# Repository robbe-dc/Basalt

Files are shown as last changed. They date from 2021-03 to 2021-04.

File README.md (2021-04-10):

# Basalt is an open source vertical computer case

Basalt was created as an open source, DIY alternative to popular SFF cases on the market. The aim is to create a small computer case with emphasis on tiny desk footprint, while still supporting today's hardware.

Basalt is made out of easy to source/create materials so it is easy to make it yourself. The main things you need are (access to) a 3D printer and a laser cutter. If you do not own these machines and do not have access to them, I advice you to try a local fablab or use online services like Shapeways, i.materialise and others.

## Hardware support

Hardware support is as following:

* ITX motherboard
* 48mm CPU cooler
* SFX(L) PSU support
* Top mounted 120mm fan
* 2x 2.5" drives up to 9mm thick
* GPU:
  * 60mm thick (3 slots) as long as the PCI bracket is 1 or 2 slot
  * 140mm high plus an extra 16mm for power connectors
  * 325mm length without top fan, 321mm with 15mm top fan, 311mm with 25mm top fan

## Getting started

* Source the materials from the [shopping list](docs/SHOPPINGLIST.md)
* Read about the [preparations](docs/PREPARATIONS.md)
* Print the required parts
* Lasercut the panels
* Build the case using the [assembly guide](docs/ASSEMBLY.md)

## Contribute

This case is open source thus contributions are encouraged. Feel free to fork this projects and create a pull request if wanted. You can also open an issue if you have aditional questions or remarks.

## Contact

Contacting me is easiest on the forum of smallforfactor.net: [Visit my profile](https://smallformfactor.net/forum/members/robbee.801/)

You can also follow the progress and discussion of the case there: [View the thread](https://smallformfactor.net/forum/threads/9l-vertical-case-that-supports-long-3-slot-graphics-card.15892)

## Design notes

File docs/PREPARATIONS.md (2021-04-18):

# Preparing the parts

Looks like you've succeeded collecting all required parts, which is a challenge to start with. Well done! Now let's get building.

## Glueing the magnets

The printed parts have a recess where the magnet will need to be glued. The smaller part hold the magnet that is glued to the 3D printed part, the larger part holds the magnet that is glued to the case panel.

The glue I used was 'UHU Max Repair' and this worked well.

To attach the magnets to the panels on the correct position, you can make use of the printed glue mold in the optional parts. You will need at least 1 normal and 1 reverse version. Refer to the image to see how to use them (most important is the position of the middle magnet as it's not symetrical).

**Important:** Make sure to triple check the polarity of the magnets before glueing. You also want to have the same polarity across all parts because the side panels are interchangable.

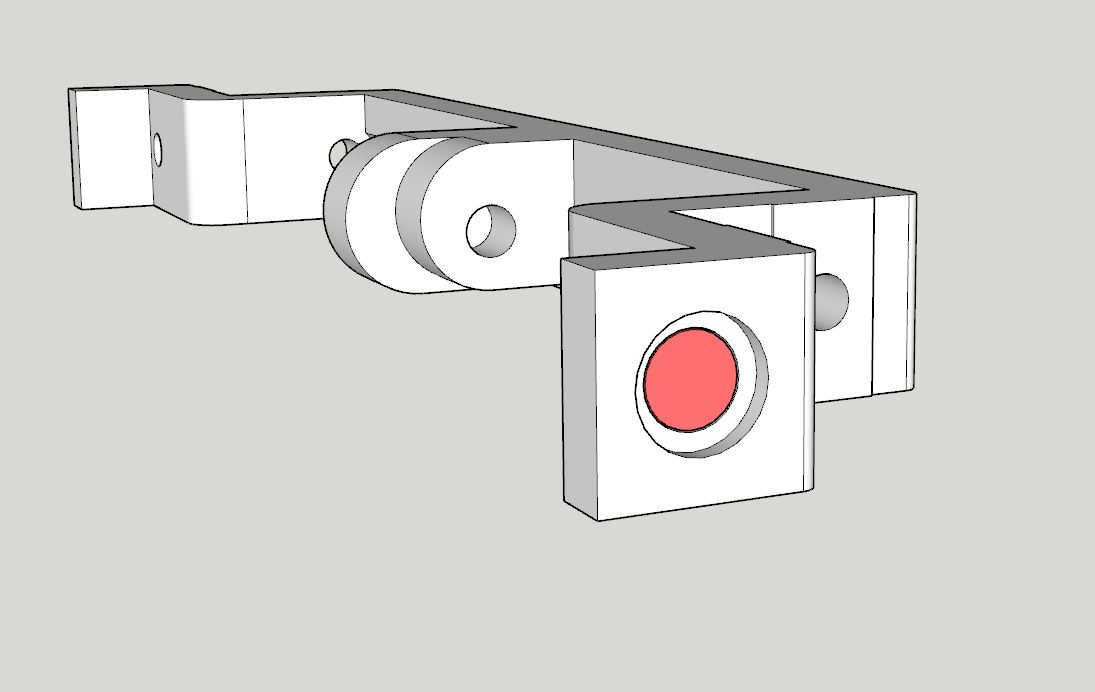
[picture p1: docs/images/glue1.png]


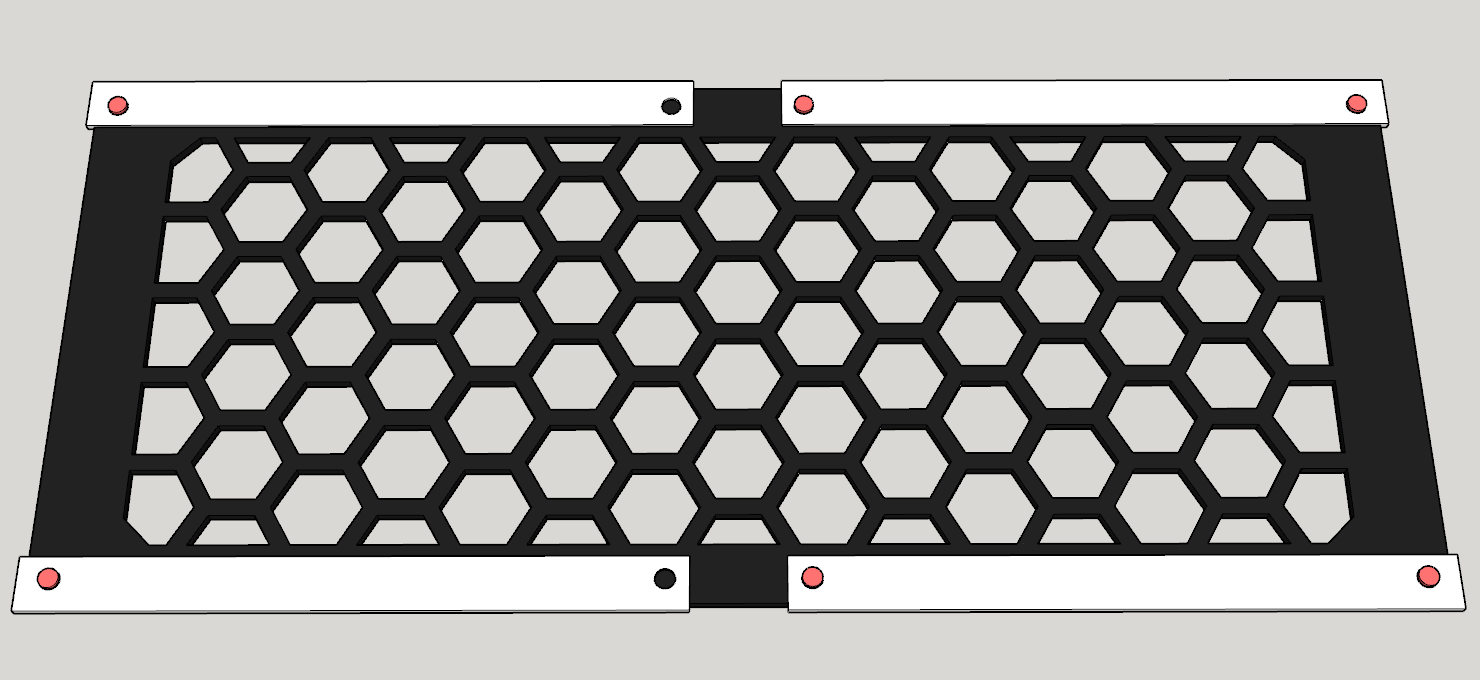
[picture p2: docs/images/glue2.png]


## Inserting threaded inserts

Threaded inserts are melted into certain parts with a soldering iron so we can screw into them without wearing out the plastic.

For a general guide about inserting threaded inserts, refer to the following movie: https://www.youtube.com/watch?v=GP1qrN-ONTA
However, I would advice you to not use so much force pushing in the inserts as we're working with smaller ones.

There are several pieces that require threaded inserts:

### Bottom

The bottom requires the following inserts:

* 2x 4mm inserts for the front IO
* 2x 4mm inserts for the GPU PCI tab
* 2x 3mm inserts for the GPU PCI clamp (above the video outputs)

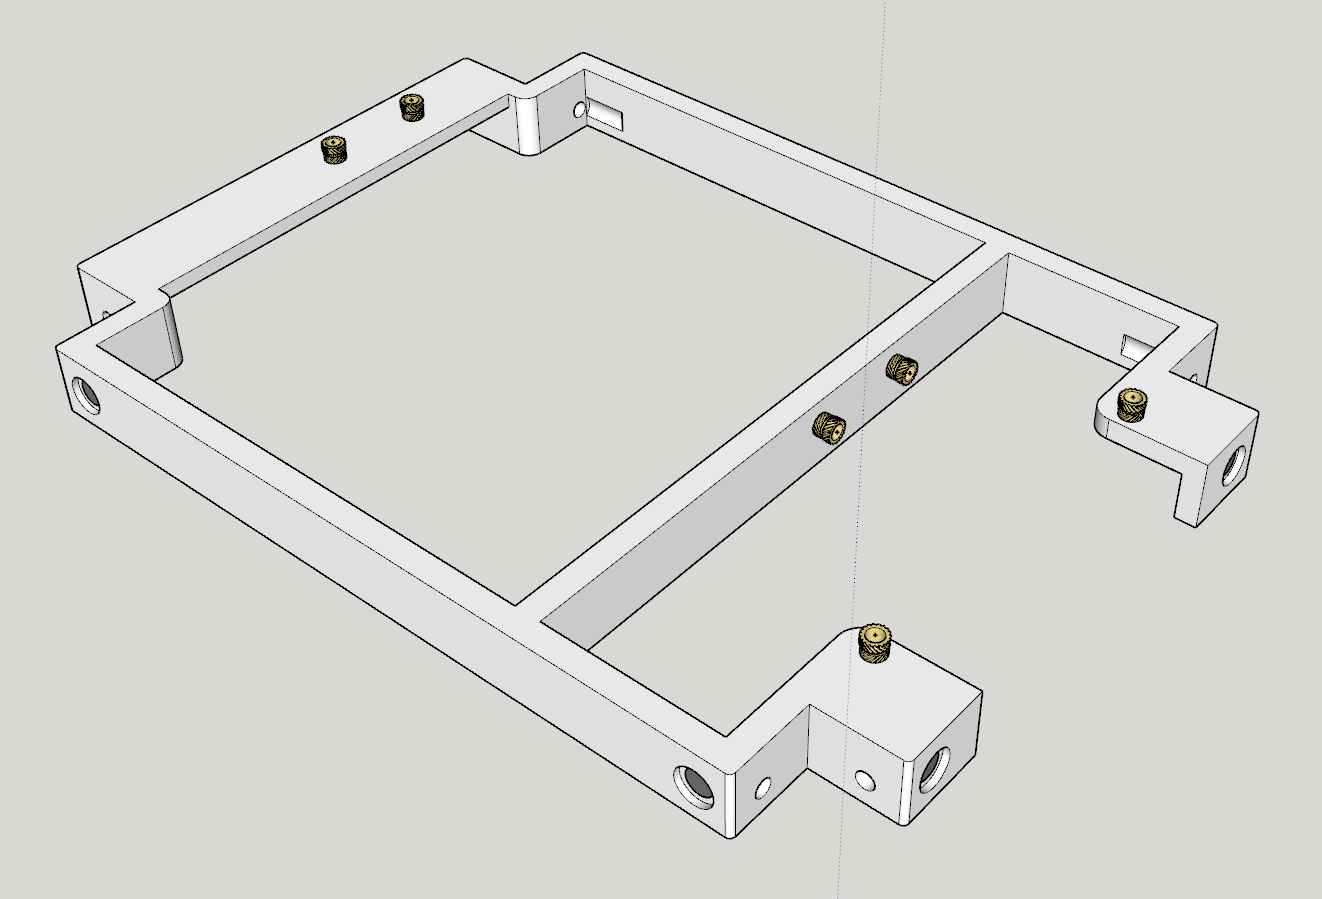
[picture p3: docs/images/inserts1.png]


### PSU Bottom

The PSU bottom needs one insert for the riser.

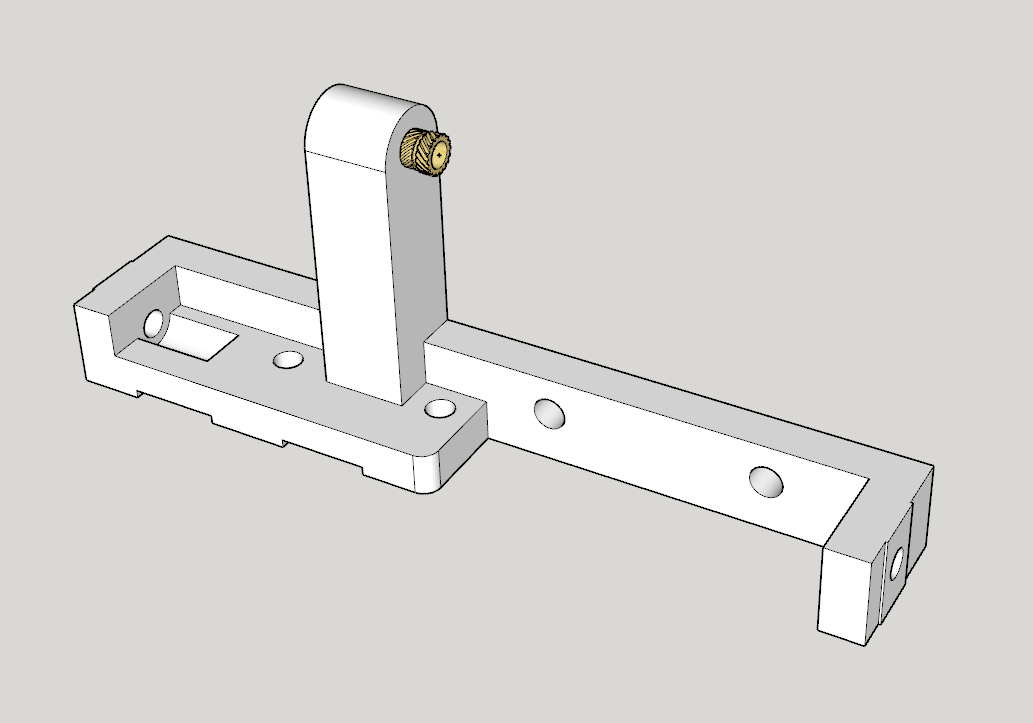
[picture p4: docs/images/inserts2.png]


### Motherboard parts x3

The three individual motherboard parts all need inserts to mount the motherboard. Make sure you check what the front and the back are so you insert the the right direction. The top of the insert should be the non-chamfered edge because that's where the motherboard comes.

The motherboard bottom back part also needs an insert for the riser.

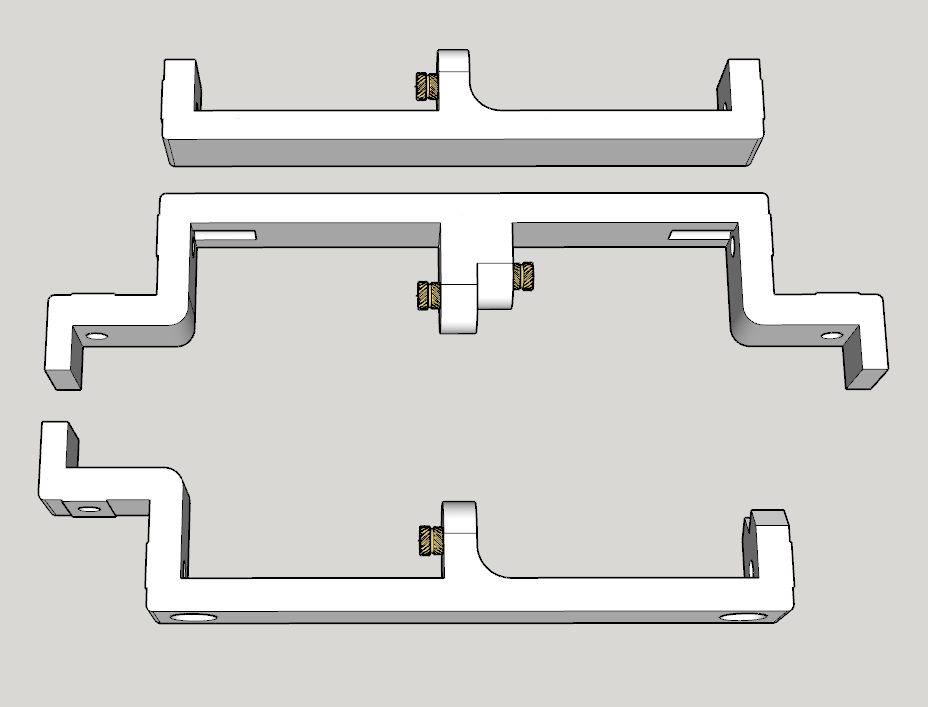
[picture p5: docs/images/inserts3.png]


### Top

Finally, the top also needs one insert for the last motherboard mount. There is no way of checking for non-chamfered sides here, but you can make out the sides because this part is not symmetrical.

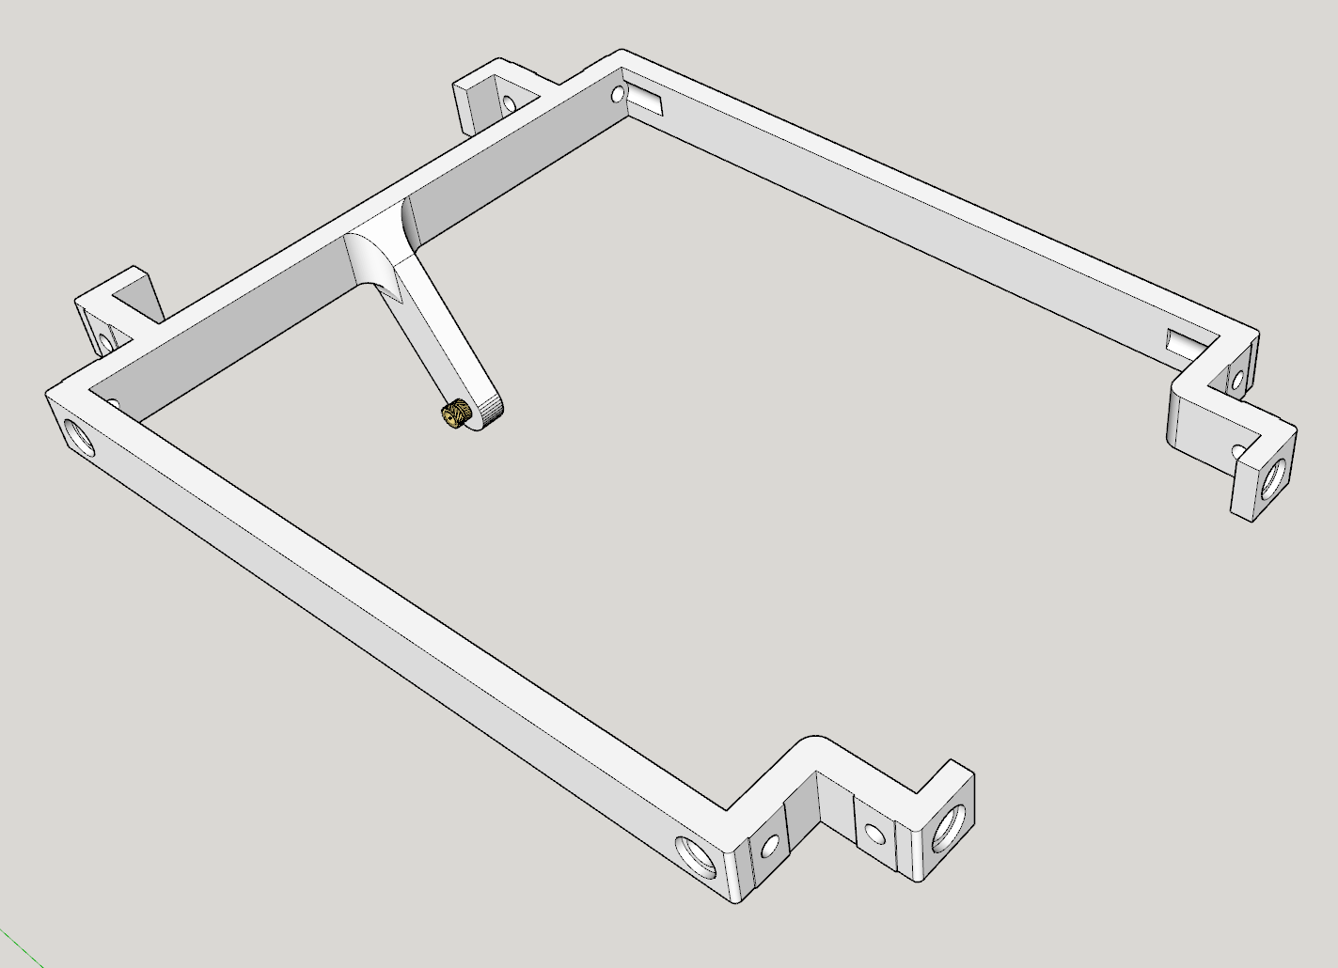
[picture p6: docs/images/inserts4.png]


## Attaching the T-nuts

The T-slot nuts will slide into the extrusion and the printed parts are then screwn into the nuts. This is hard to do when the nuts slide all over the place, so I prefer to attach the nuts to the parts before sliding them into the extrusion.

You can do so by screwing the nuts to the part with the M3x10mm screws, but don't tighten it yet as you won't be able to slide them in the extrusion anymore. Do this for all parts that require T-slot nuts, which are the following:

* Bottom: 8 nuts
* PSU bottom: 2 nuts
* PSU top: 1 nut
* Motherboard bottom back: 4 nuts
* Motherboard bottom front: 3 nuts + 1 nut for the optional piece
* Motherboard top front: 2 nuts
* Top: 8 nuts
* (optional) GPU holder: 2 nuts (see opional pieces for more info)

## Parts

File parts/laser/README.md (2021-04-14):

# Laser cut panels

You will need to cut these 6 panels out of 3mm thick acrylic or wood. The dimensions can be found in the readme file of each panel

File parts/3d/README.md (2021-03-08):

# 3D printed parts

This folder contains each required 3D printed part for the case. Each folder has its own readme file with print instructions for the specific file.

## Print settings and material

Preferably, print this in PETG with at least 3 perimeters. Infill won't matter a lot because there is so little of it.

I have also made versions in PLA but found them to be a bit too brittle and the adhesion between layers was a bit too weak to withstand the force of the screws.

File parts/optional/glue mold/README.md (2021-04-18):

# Glue mold

This mold is used to align the magnet on the panels when glueing them. Refer to the [preparations](../../../docs/PREPARATIONS.md) documentation for info on how to use it.

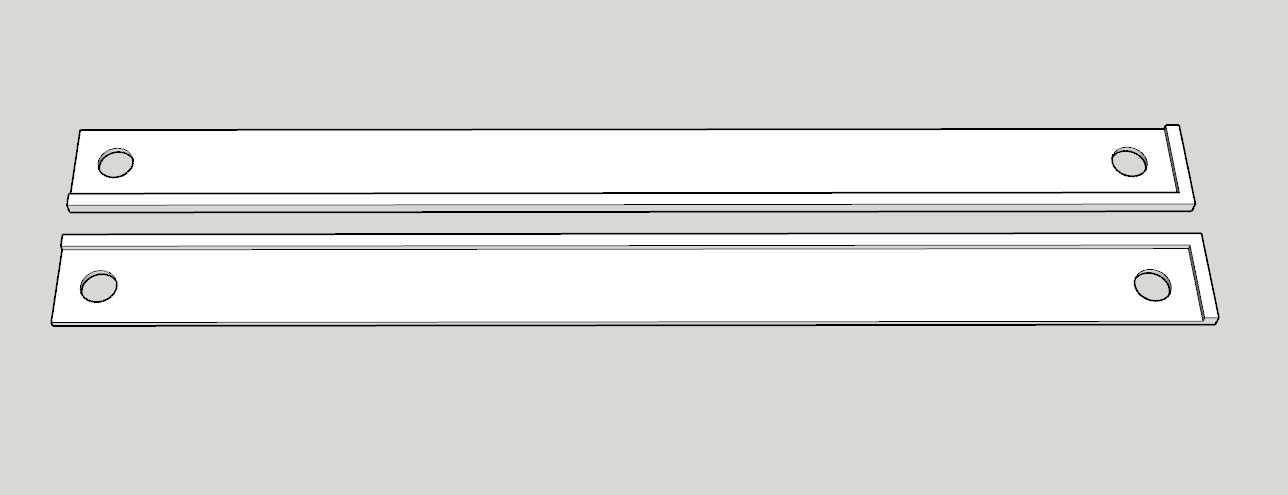
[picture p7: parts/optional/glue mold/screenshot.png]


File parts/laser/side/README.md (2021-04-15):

# Side panel

This panel is symmetric so you cut one for each side.

Width: 147mm
Height: 350mm

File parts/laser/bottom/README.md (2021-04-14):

# Bottom panel

Width: 188mm
Height: 137mm

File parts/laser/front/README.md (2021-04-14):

# Front panel

Width: 96mm
Height: 350mm

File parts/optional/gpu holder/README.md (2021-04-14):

# GPU holder

This is a special part that can be used to mount the rear of the GPU to the case so it is very firmly held into place. This requires your GPU to have special mounting points used for server mounting. Most Nvidia GPU's have those mouning points and some AMD cards as well.

Those screw holes are usually M3 and you best use countersunk screws to avoind interferance with the top fan.

To know if your GPU has these mounting points, refer to the following images:

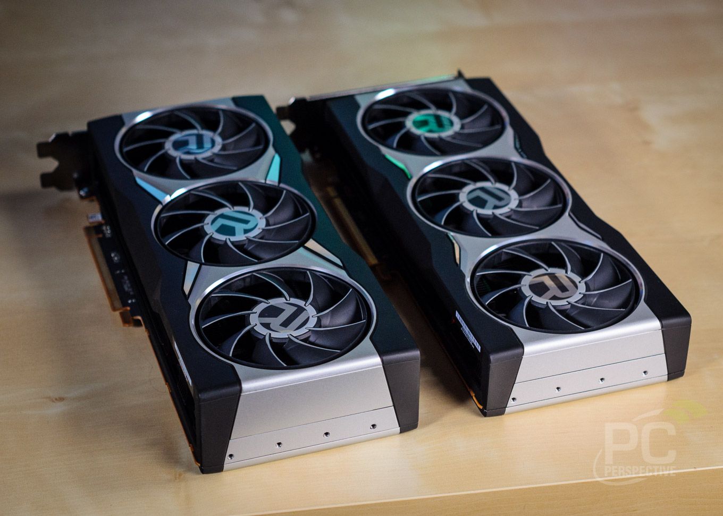
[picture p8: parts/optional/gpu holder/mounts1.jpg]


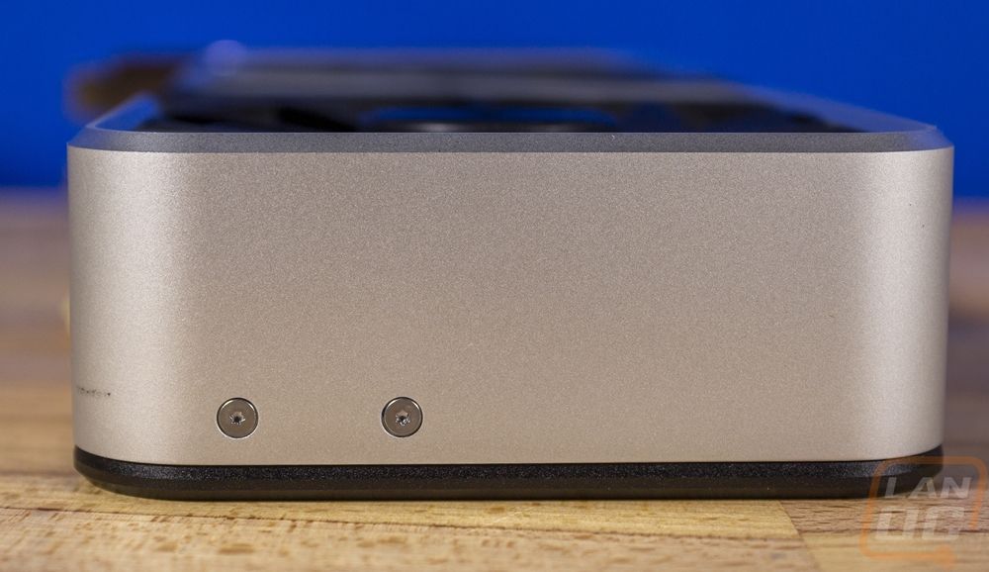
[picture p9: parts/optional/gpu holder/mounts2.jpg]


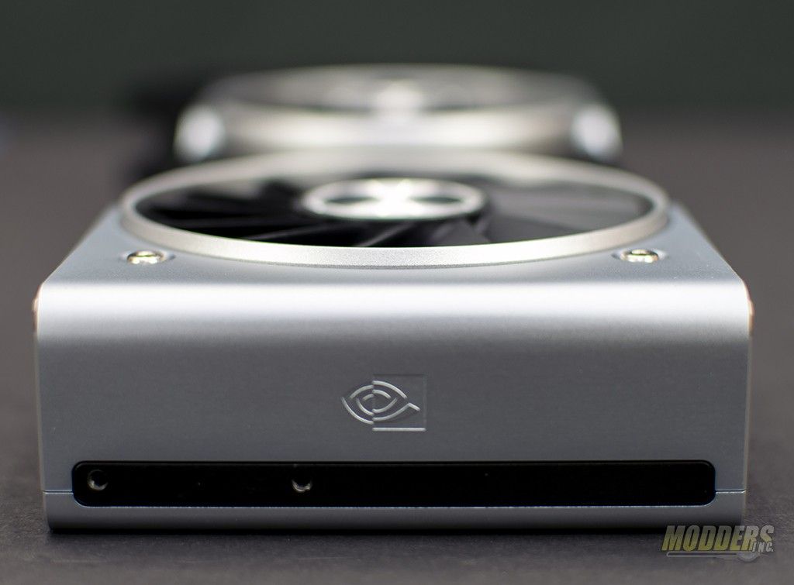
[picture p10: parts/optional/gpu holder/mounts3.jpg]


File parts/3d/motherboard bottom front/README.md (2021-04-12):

# Motherboard bottom front

This part connects the motherboard bottom front to the 2 front extrusions and has room for 4 magnets for the front and 2 side panels.

This part is split up in 2 parts so that you can ommit the smaller part when you have a very tall and thick GPU.

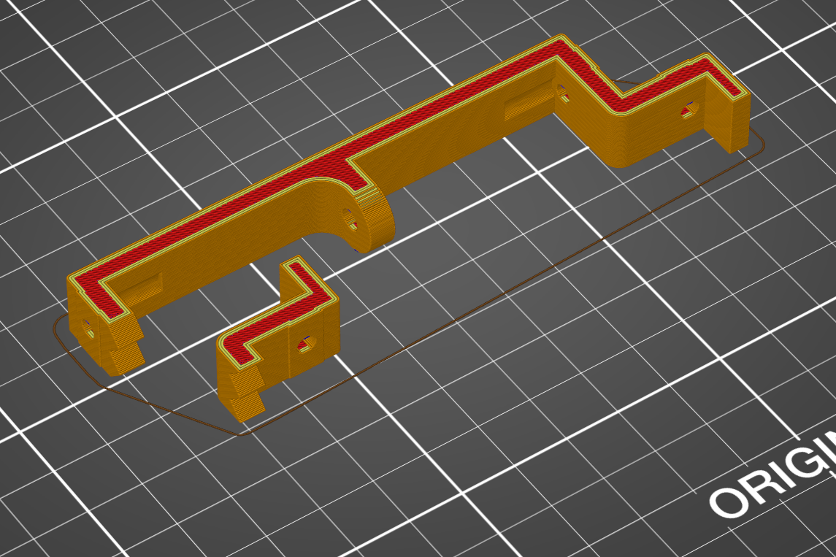
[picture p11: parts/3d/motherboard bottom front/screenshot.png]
Slicer screenshot


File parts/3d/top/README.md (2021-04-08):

# Top

This important part holds the 4 extrusions together, holds 8 magnets for all panels and supports the top back corner of the motherboard.

This part is pretty easy to print. No support required, a brim of about 5mm could be prefered if your printer is prone to prints warping.

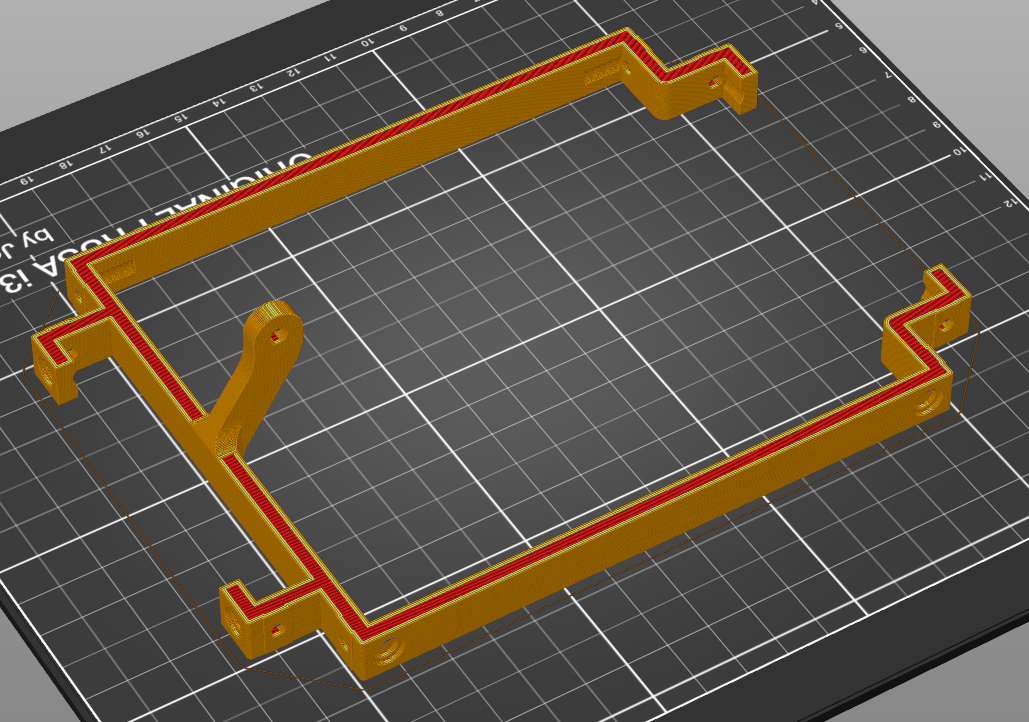
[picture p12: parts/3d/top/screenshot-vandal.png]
Slicer screenshot


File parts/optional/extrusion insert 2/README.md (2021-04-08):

# Extrusion insert 2

This insert should be printed twice and goes in the front top, between the motherboard bottom front and the motherboard top front.

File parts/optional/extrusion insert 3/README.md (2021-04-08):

# Extrusion insert 3

This insert goes in the back bottom, between the PSU bottom and the PSU top.

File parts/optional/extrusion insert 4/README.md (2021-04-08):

# Extrusion insert 4

This insert goes in the back bottom, between the PSU bottom and the motherboard bottom back.

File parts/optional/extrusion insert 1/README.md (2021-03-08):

# Extrusion insert 1

This insert should be printed twice and goes in the bottom front, between the bottom and the motherboard bottom front parts.

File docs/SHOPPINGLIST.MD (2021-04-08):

# Items required for the Basalt:

Note: items that are used in high numbers include some spares.

Item | Amount | Size | Note
---- | ------ | ---- | ----
GPU riser|1|About 18cm long|Any riser with 108mm hole spacing that is either straight or double reverse (eg. ADT-Link, Li-Heat, Linkup)
Video output extensions|1 or 2|5 to 10 cm|Important: refer to the [guide](#about-the-video-extension-cables) under this table for more info
Rounded aluminium extrusions|4|350mm long, 20x20|Can be bought on [Motedis](https://www.motedis.com/shop/Aluprofile/Aluprofil-20x20-LR-B-Typ-Nut-6::4.html) (EU), [Misumi](https://us.misumi-ec.com/vona2/detail/110302685570/?Tab=codeList) (US), [Aliexpress](https://nl.aliexpress.com/item/32837930160.html)
T-slot inserts|About 30|Preferably M3|Best get some spares. Can be bought on Motedis (EU), Misumi (US), Aliexpress
Case feet|4|Depends on the tap size of your extrusions|I used [these](https://aliexpress.com/item/4001184672773.html?) (M6*15). Smaller taps can also use feet like [these](https://aliexpress.com/item/33060530969.html)
Round magnets|About 50|5mm diameter, 1mm thick|
Threaded inserts|8|M3, 4mm long|[Aliexpress](https://aliexpress.com/item/4001258499799.html)
Threaded inserts|2|M3, 3mm long|[Aliexpress](https://aliexpress.com/item/4001258499799.html)
Screws|10|M3 x 5mm|Non countersunk, philips head
Screws|About 40|M3 x 10mm|Non countersunk, philips head
Screws|4|M4 x 10mm|Countersunk
Screws|8|The size of your extrusion taps

## About the video extension cables

The video extension cables come from ADT-Link. You should buy cables that have an angled male connector form your GPU on one side and a threaded female connector on the other side. ADT-Link connectors are easy to find on Aliexpress.

When using 1 cable, the cable should be 5cm long and it doesn't really mather what angle you pick. I went with a 5cm P3 to P4T displayport cable.

When using 2 cables, it gets a bit more complicated. The first cable should be 5cm long and the angle isn't too important again. The second cable should use the opposite angle and should be 10cm long. This allows for much easier cable routing because they don't have to cross eachother.

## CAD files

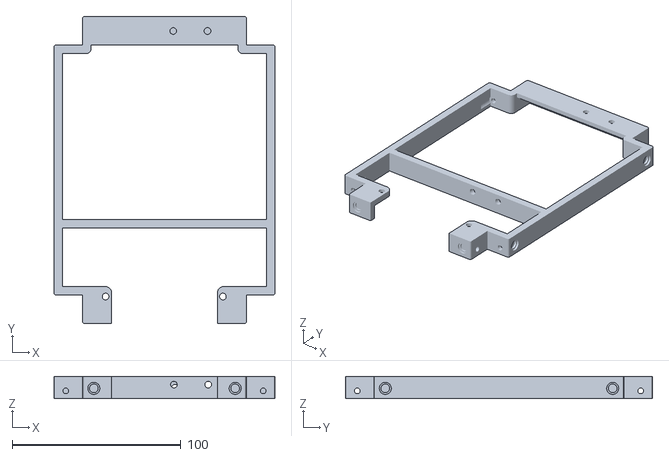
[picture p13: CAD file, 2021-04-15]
parts/3d/bottom/bottom.stl
131.0 x 182.0 x 13.2

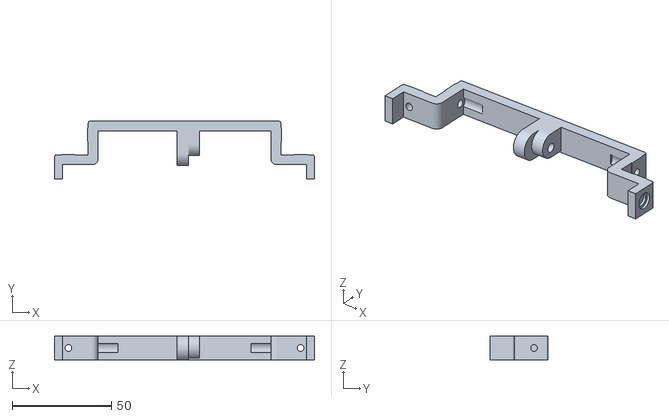
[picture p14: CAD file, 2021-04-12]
parts/3d/motherboard bottom back/motherboard bottom back.stl
131.0 x 29.2 x 12.0

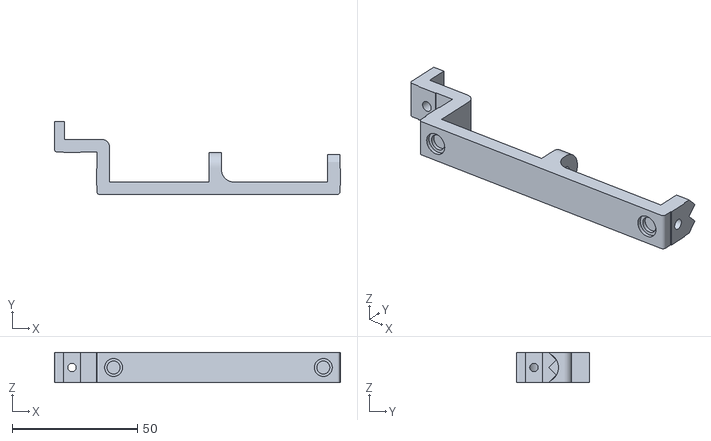
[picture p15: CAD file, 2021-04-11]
parts/3d/motherboard bottom front/motherboard bottom front.stl
114.3 x 29.2 x 12.0

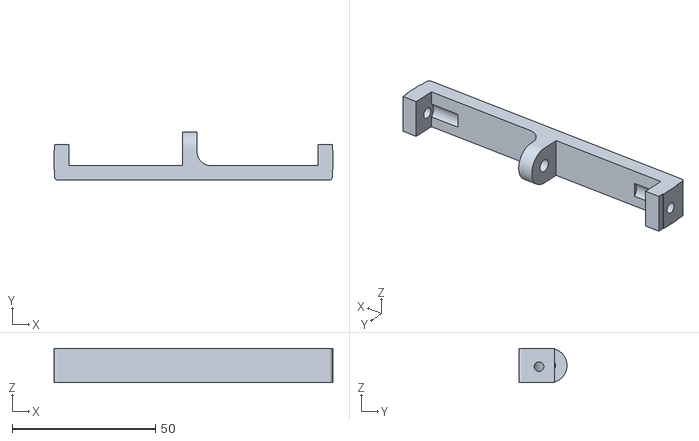
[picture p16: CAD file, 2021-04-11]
parts/3d/motherboard top front/motherboard top front.stl
97.5 x 16.8 x 12.0

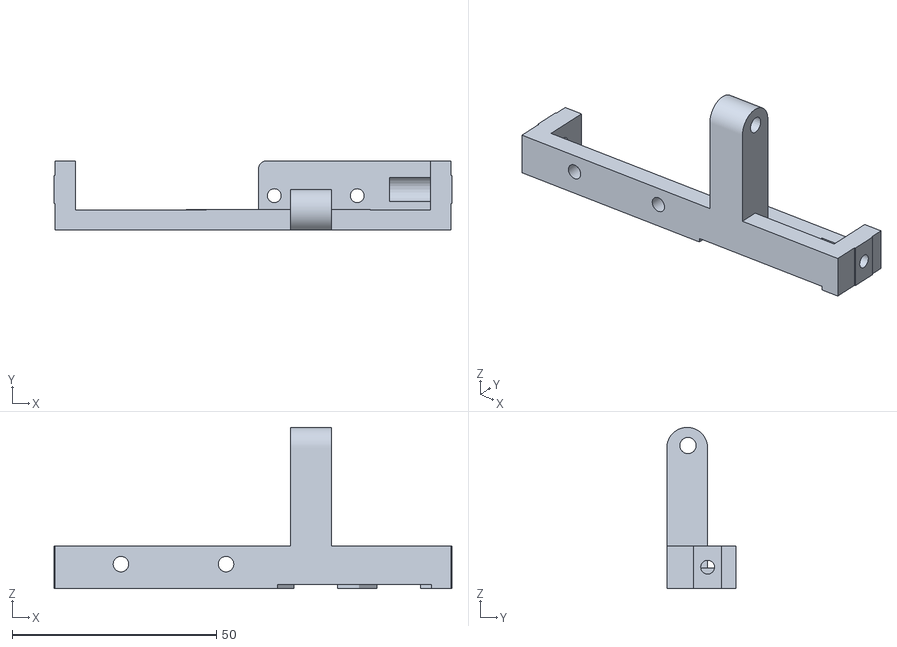
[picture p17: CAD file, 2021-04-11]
parts/3d/psu bottom/psu bottom.stl
97.5 x 17.0 x 39.5

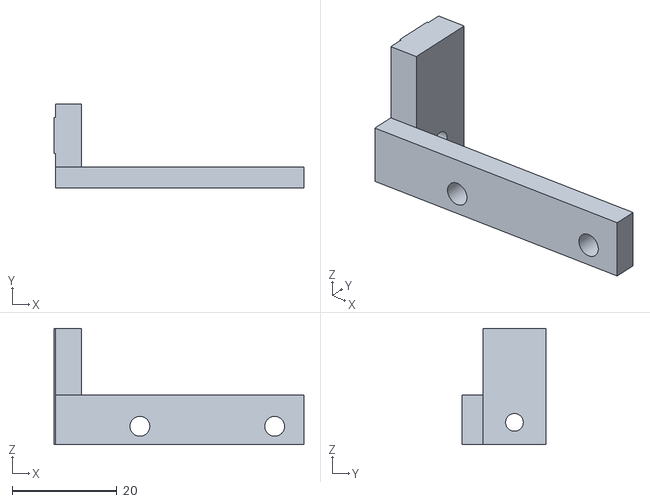
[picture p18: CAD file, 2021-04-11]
parts/3d/psu top/psu top.stl
47.8 x 16.0 x 22.2

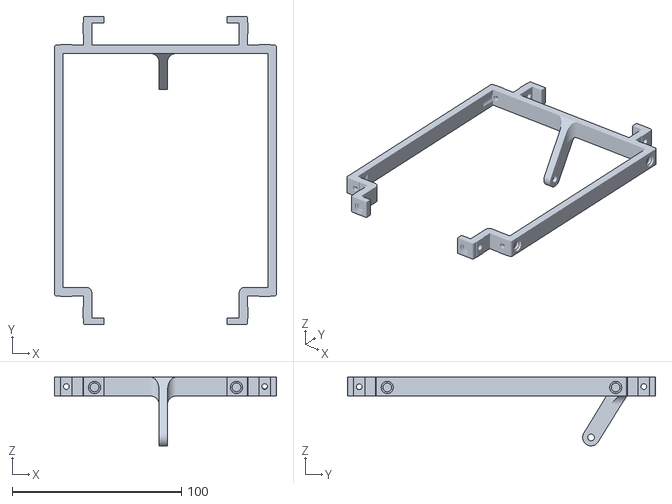
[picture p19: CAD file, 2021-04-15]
parts/3d/top/top.stl
131.0 x 182.0 x 40.6

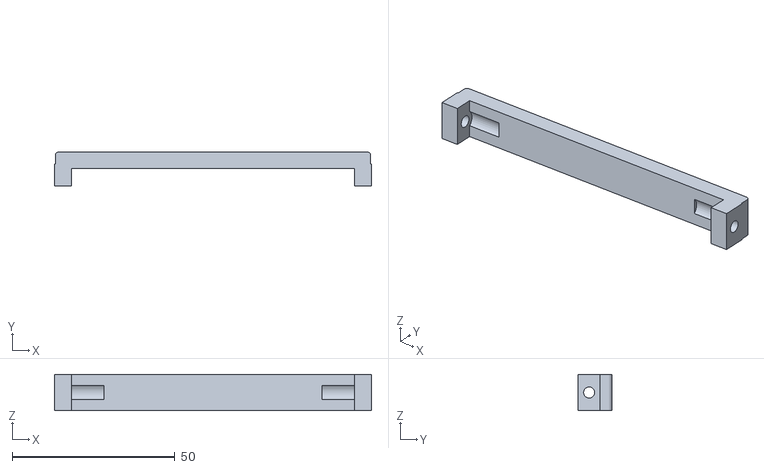
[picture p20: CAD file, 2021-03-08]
parts/optional/cable holder/cable holder.stl
97.5 x 10.4 x 11.2

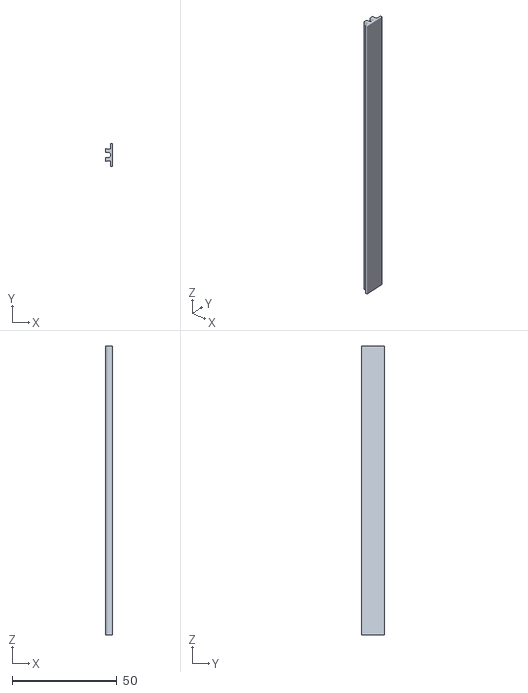
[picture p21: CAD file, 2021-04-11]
parts/optional/extrusion insert 1/extrusion insert 1.stl
3.50 x 10.8 x 137.7

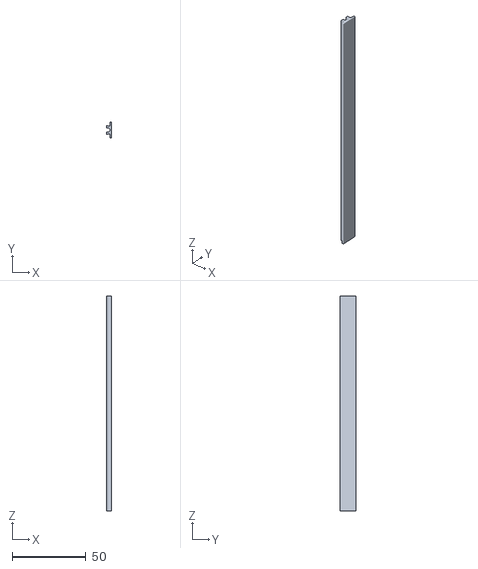
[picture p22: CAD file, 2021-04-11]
parts/optional/extrusion insert 2/extrusion insert 2.stl
3.50 x 10.8 x 145.5

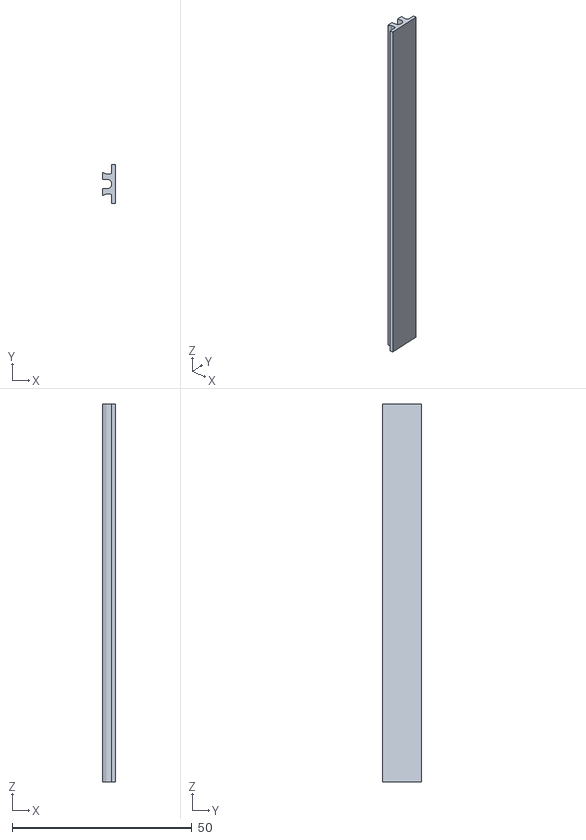
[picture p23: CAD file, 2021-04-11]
parts/optional/extrusion insert 3/extrusion insert 3.stl
3.50 x 10.8 x 105.0

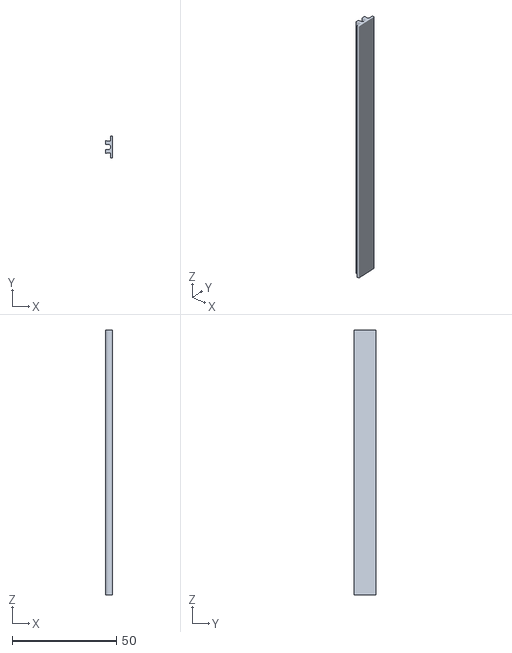
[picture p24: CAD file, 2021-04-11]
parts/optional/extrusion insert 4/extrusion insert 4.stl
3.50 x 10.8 x 127.2

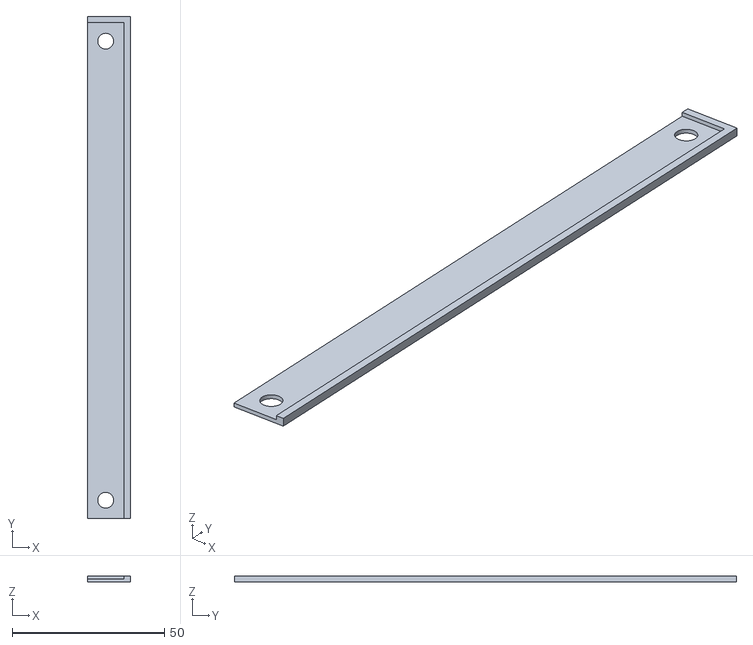
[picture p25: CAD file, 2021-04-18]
parts/optional/glue mold/glue mold.stl
14.0 x 164.9 x 2.00

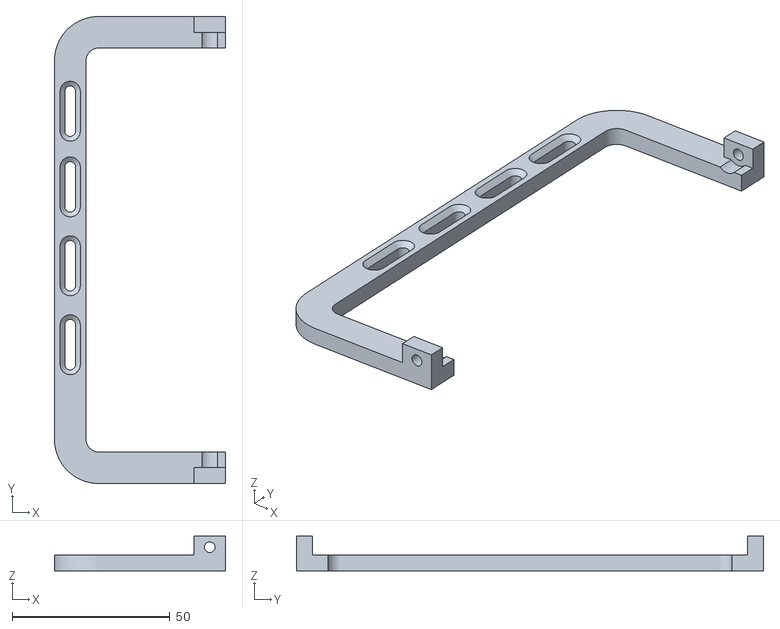
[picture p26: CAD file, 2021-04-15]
parts/optional/gpu holder/gpu holder.stl
54.2 x 148.0 x 11.0

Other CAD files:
parts/3d/motherboard bottom front/motherboard bottom front magnet.stl
parts/optional/glue mold/glue mold reverse.stl

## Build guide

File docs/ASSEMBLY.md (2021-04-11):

# Building Basalt

This guide is split up in 2 parts: [assembling the case](#assembly) and [inserting the hardware](#inserting-the-hardware).

## Assembly

Start by attaching the extrusions to the bottom part. Be careful at this point because the extrusions won't be held into place very well yet so they may fall over and damage the attached parts in the process.

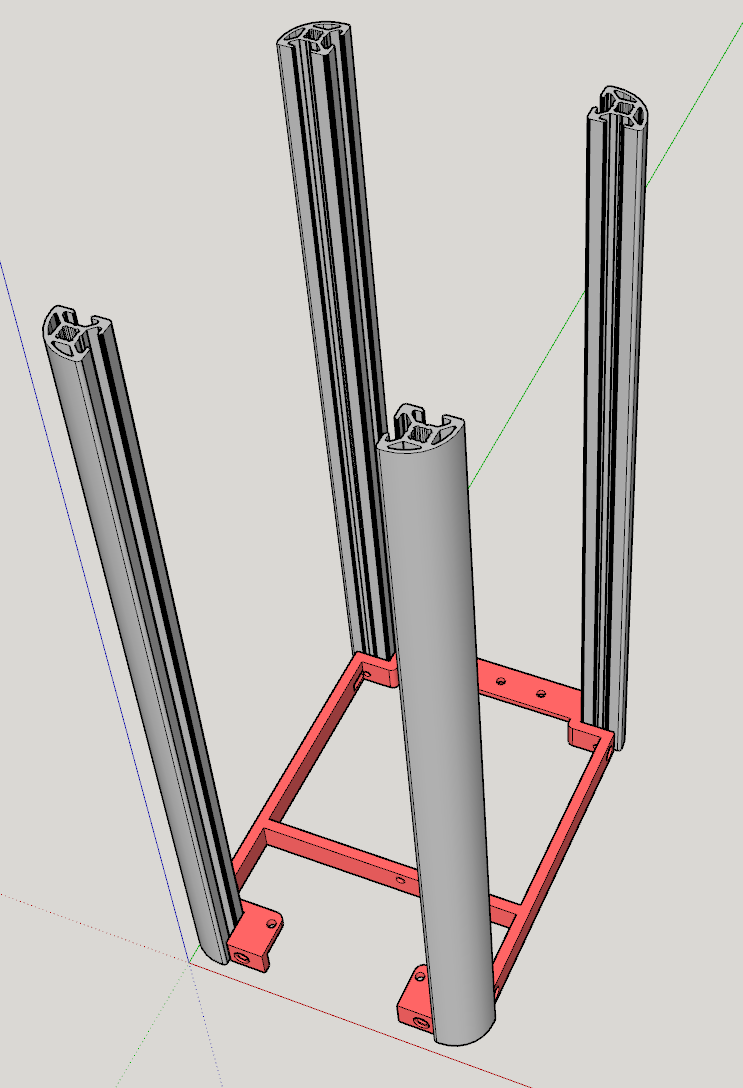
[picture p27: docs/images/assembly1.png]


We'll go on with the front. You'll have to slide the parts in the extrusions from the top of the case from now on.

If you have printed the extrusion inserts, now is the time to insert the two number 1s in the front. If you haven't please consider again because this is hard without and you'll have to use the hardware later on to get the measurements.

With the extrusion inserts into place, you can now attach the motherboard bottom front.

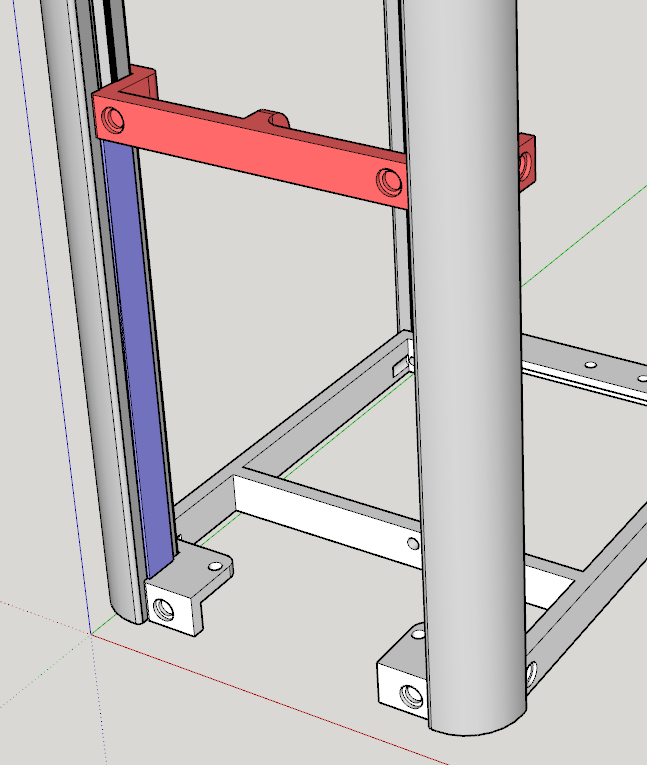
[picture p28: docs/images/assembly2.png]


Next, insert both extrusion inserts labeled number 2. You'll now know where to attach the motherboard top front part.

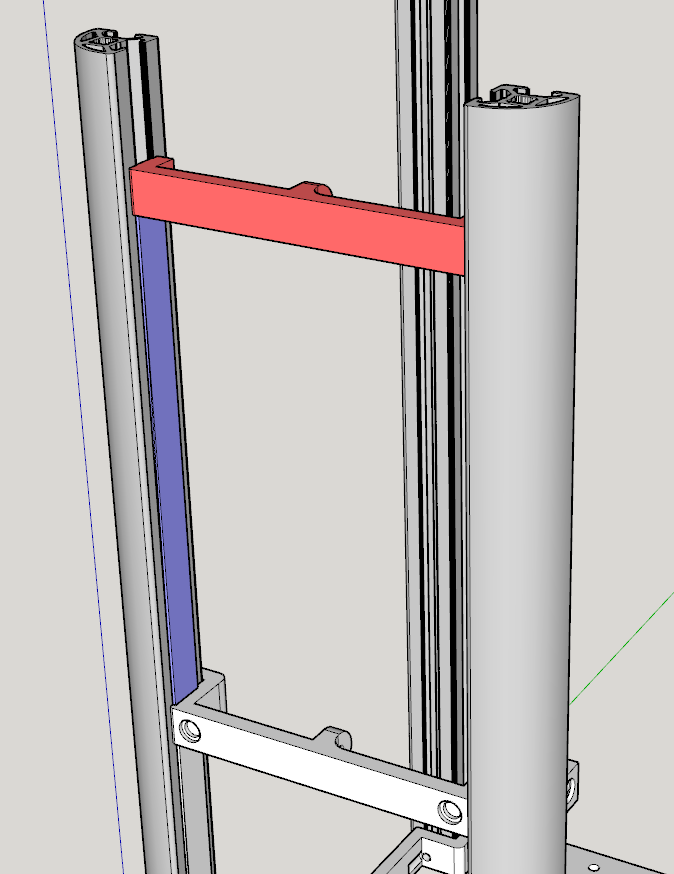
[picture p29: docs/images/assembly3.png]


Before attaching the top, we'll first have to attach the back parts.

The PSU bottom part is first. Don't tighten this too hard yet, we'll have to loosen it again to insert the GPU later on when assembling the hardware.

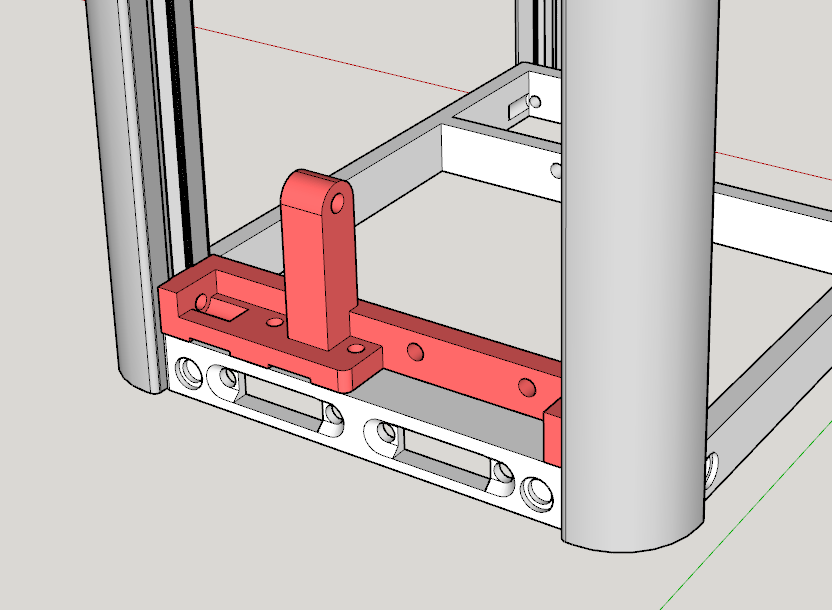
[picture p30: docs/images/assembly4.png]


Insert the extrusion insert number 3 on the motherboard side and then the PSU bottom on top.

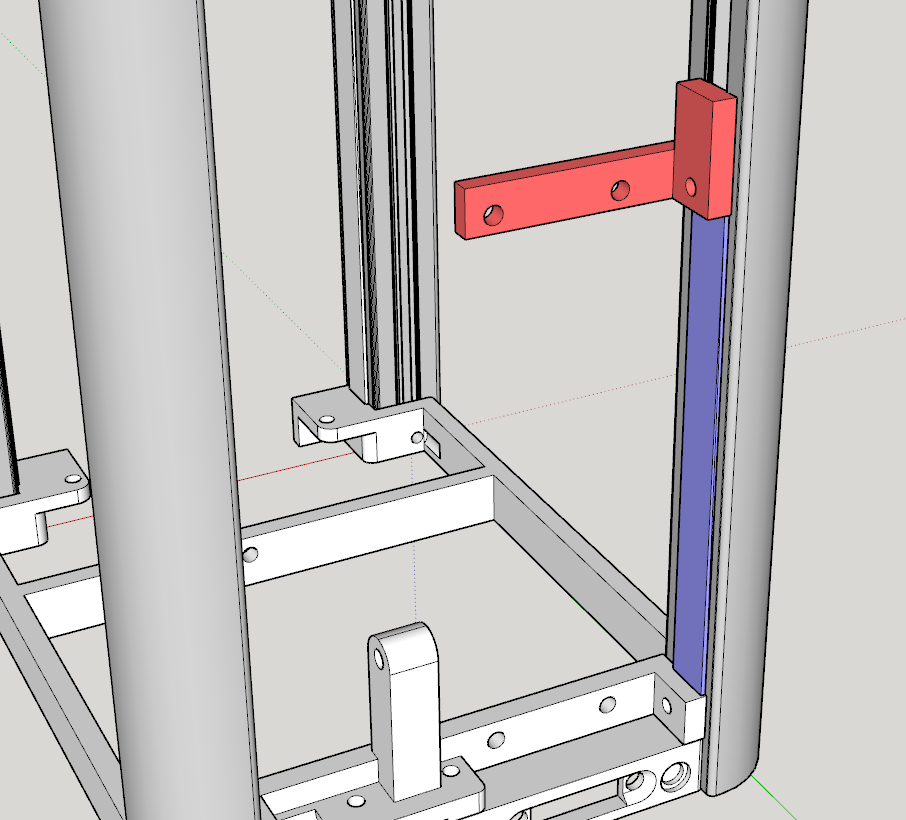
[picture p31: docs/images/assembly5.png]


Insert number 4 goes on the GPU side and the motherboard bottom back should rest on the PSU top part and the extrusion insert.

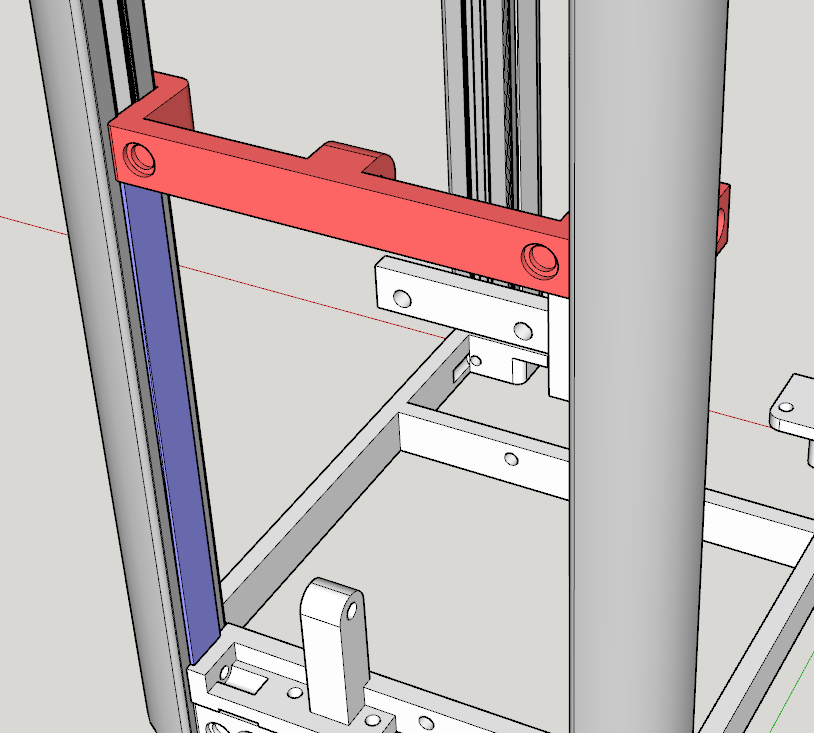
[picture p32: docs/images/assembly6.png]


The final piece, the top, should be aligned nicely with the top of the extrusions and thus need no extrusion inserts.

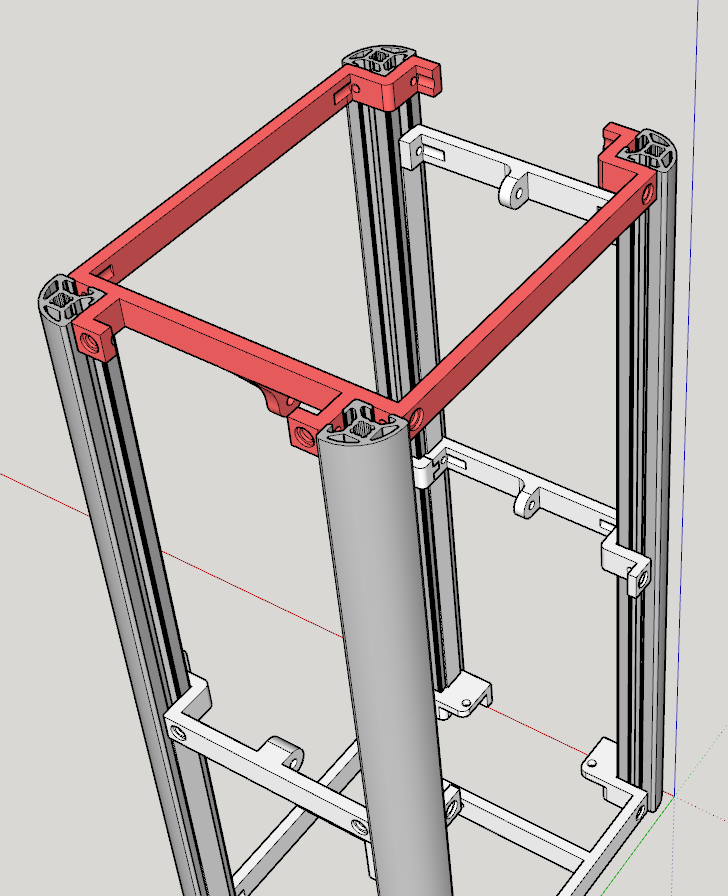
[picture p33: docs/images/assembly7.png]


Only thing left now is the accessories: the front I/O and the riser. We won't be able to insert the riser before the GPU is mounted, so we'll only mount the front I/O for now.

The front I/O simply screws into the bottom part on the front. Make sure to insert it upside down or it won't line up with the front panel.

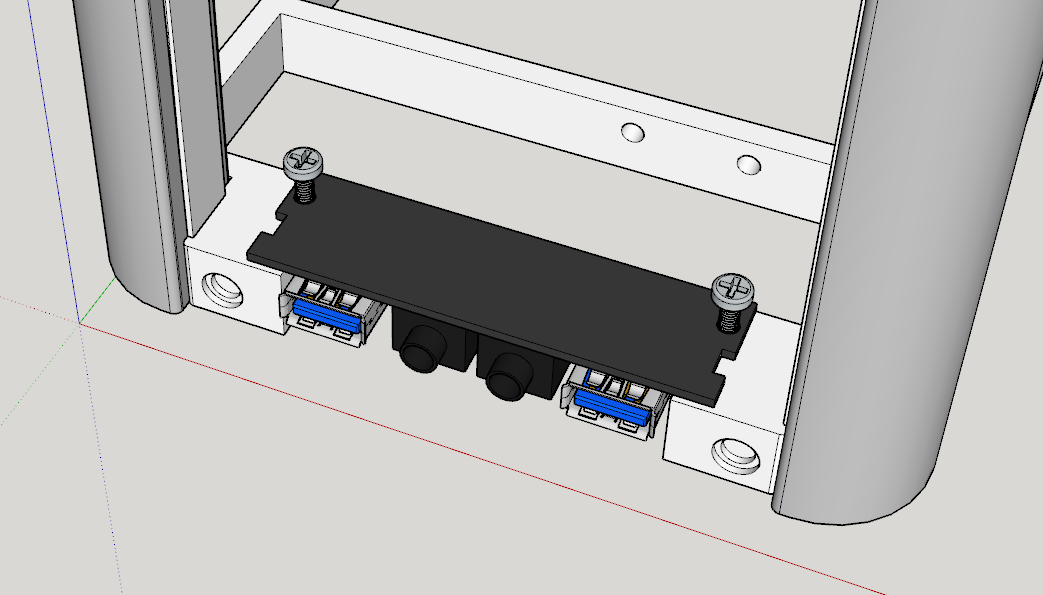
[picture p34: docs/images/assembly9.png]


## Inserting the hardware

To insert the hardware, we'll temporarily take out the top printed part. We'll insert it again throughout the hardware process.

**GPU**

We'll start out with the largest part, the GPU. The easiest is to insert the GPU itself is at an edge from the side of the case. If you have a very large card, this may not be possible. I would then advice to insert it from the top but be carefull not to damage parts with the PCI bracket.

To insert the GPU, we first have to slide up the PSU bottom part a bit because the PCI tab will have to come between the bottom part and the PSU bottom part. You may to temporarily take out the extrusion insert that keeps it into place for this.

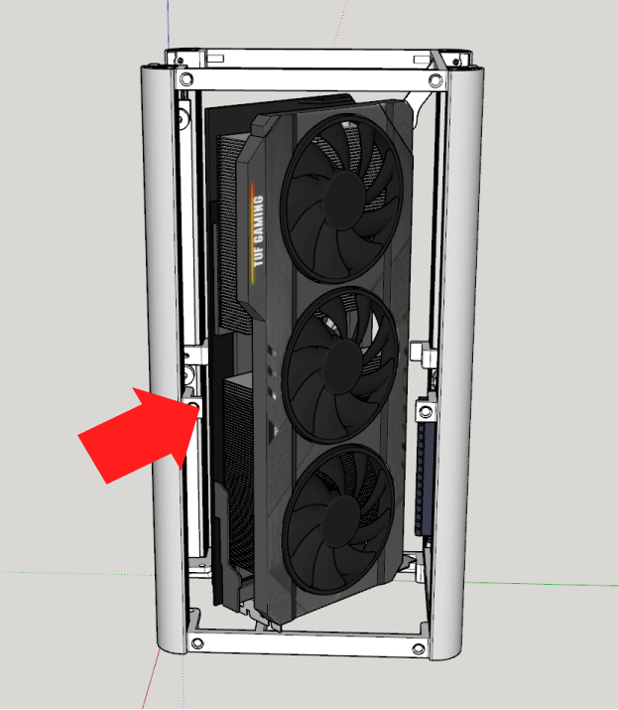
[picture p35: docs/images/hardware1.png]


Push the PSU bottom all the way down and make sure the PCI bracket is held well into place. Screw the PSU bottom part into the extrusions and the bottom and insert the extrusion inserts again.

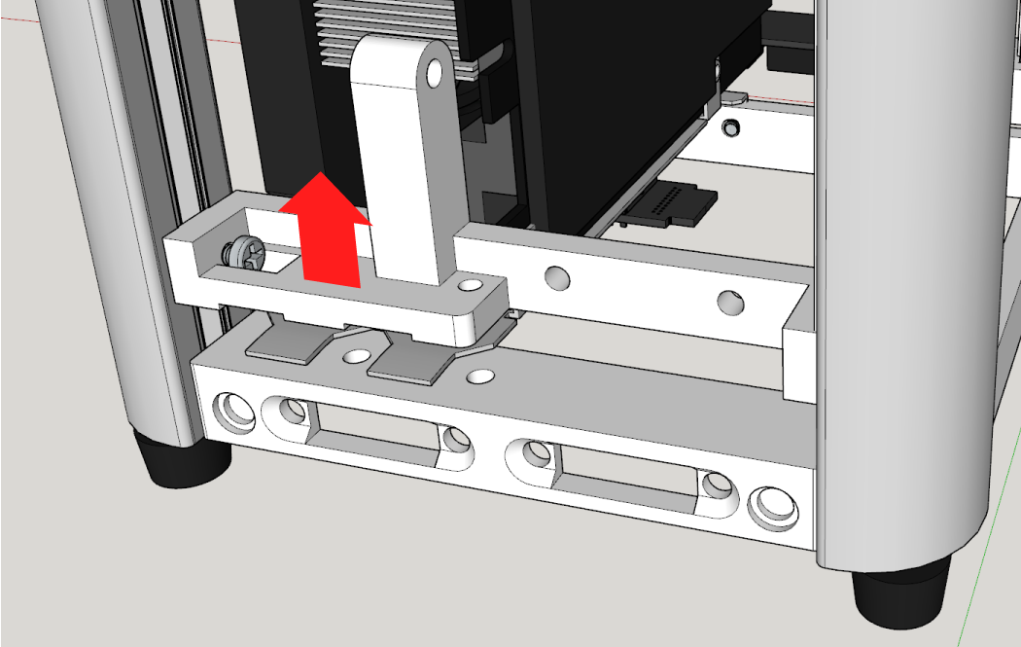
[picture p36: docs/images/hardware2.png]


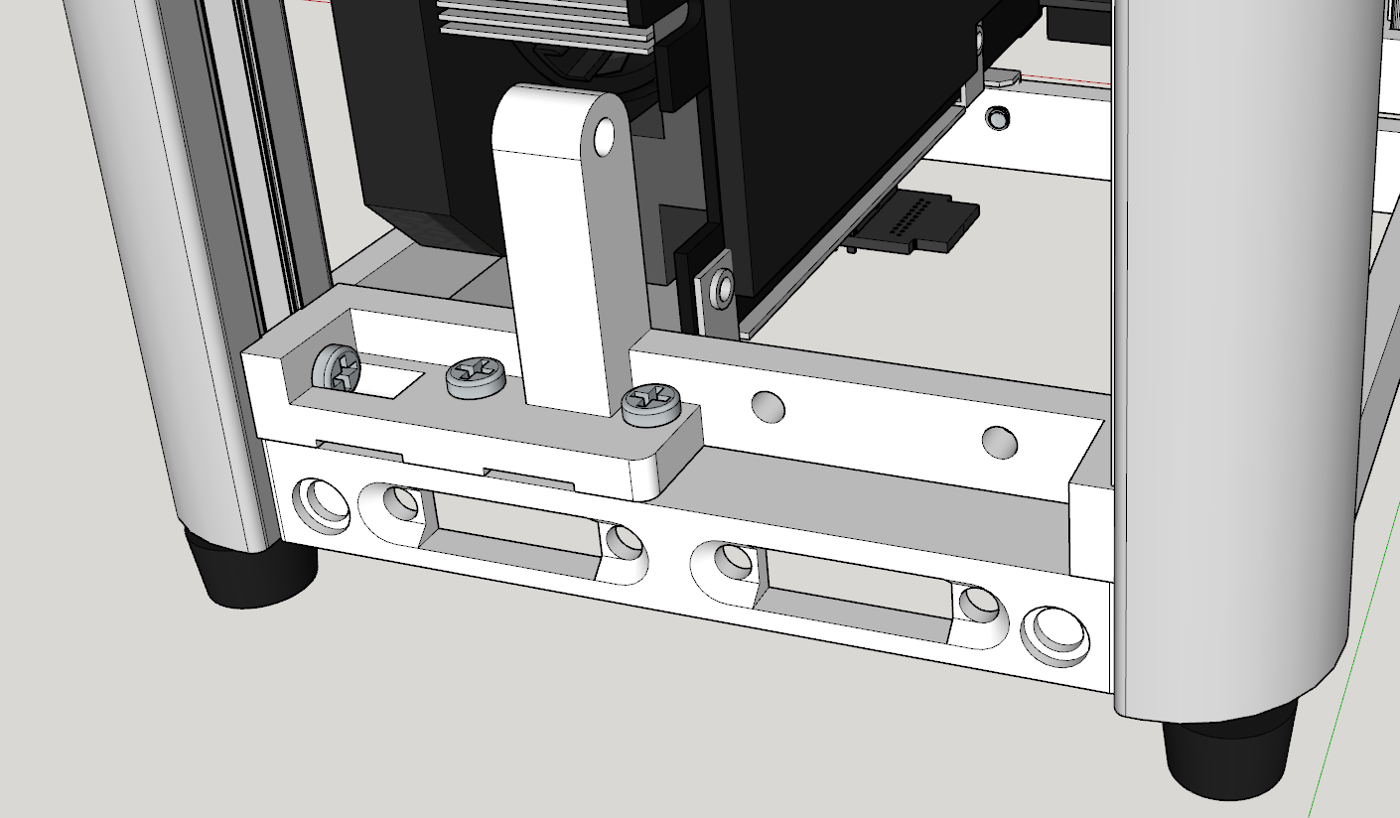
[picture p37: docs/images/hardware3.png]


Now we can also attach the riser to the GPU and screw it into the PSU bottom part and the motherboard bottom back.

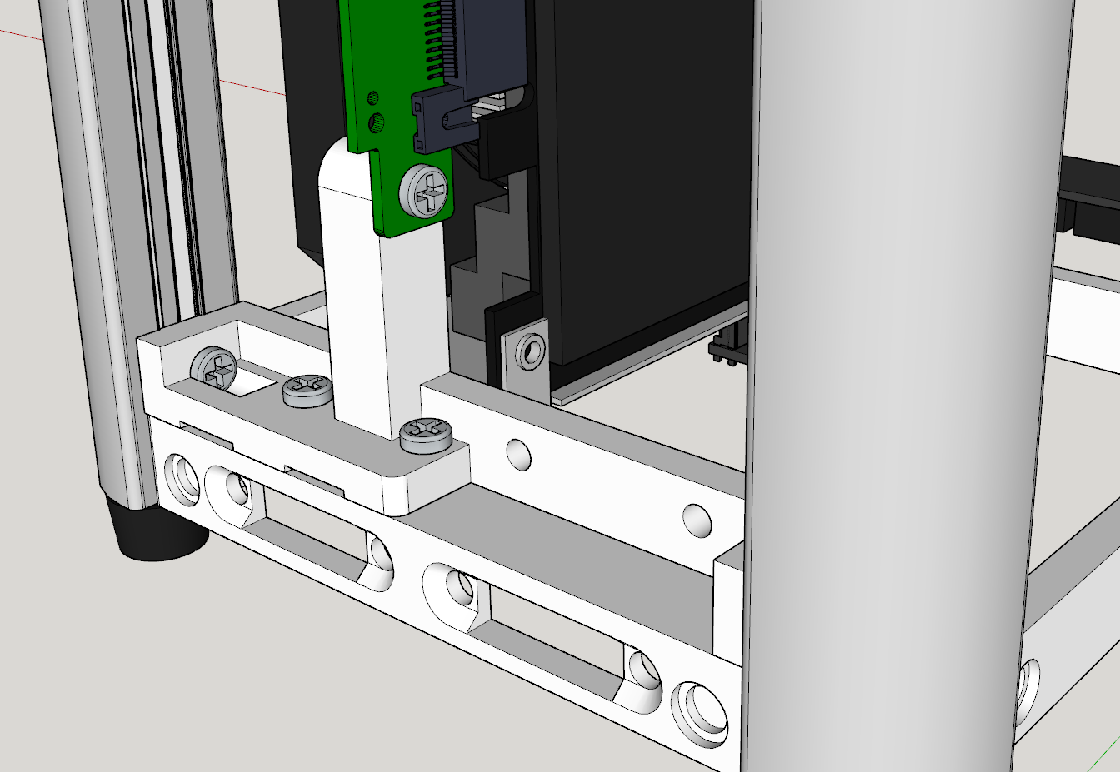
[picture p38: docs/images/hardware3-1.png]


Screw in the PCI tab on the bottom. If the front I/O is too inconvinient, you can also temporarily take it out.

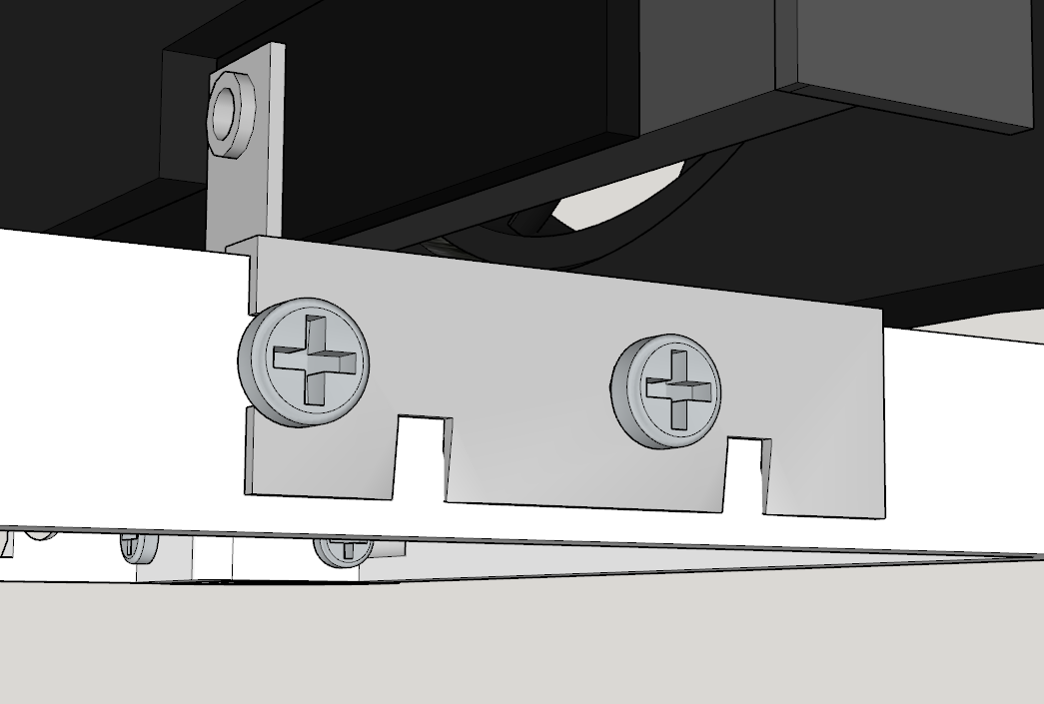
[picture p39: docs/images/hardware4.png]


**Motherboard**

The motherboard goes in next. Install the memory and CPU cooler before you put it into the case. If your CPU cooler blocks access to certain ports, insert those cables already.

The board is inserted from the top and at this point there should be only 3 mounting points available. After you've screwed the board to those 3 points, you can insert the top part again and screw the board to the fourth point.

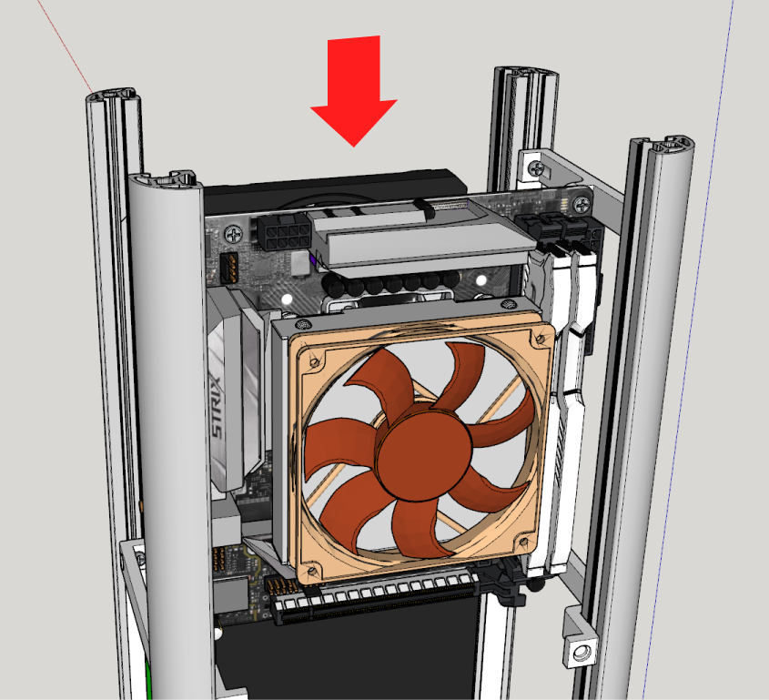
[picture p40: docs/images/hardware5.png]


Now comes a tricky part: the riser cable. Lay it out horizontally so you can see where the bend needs to come. Start by gently bending the riser and lining it up with the PCI connector on the motherboard. When you're certain the it's lined up well, pinch the bend together so it gets as tight as possible without damaging the riser.

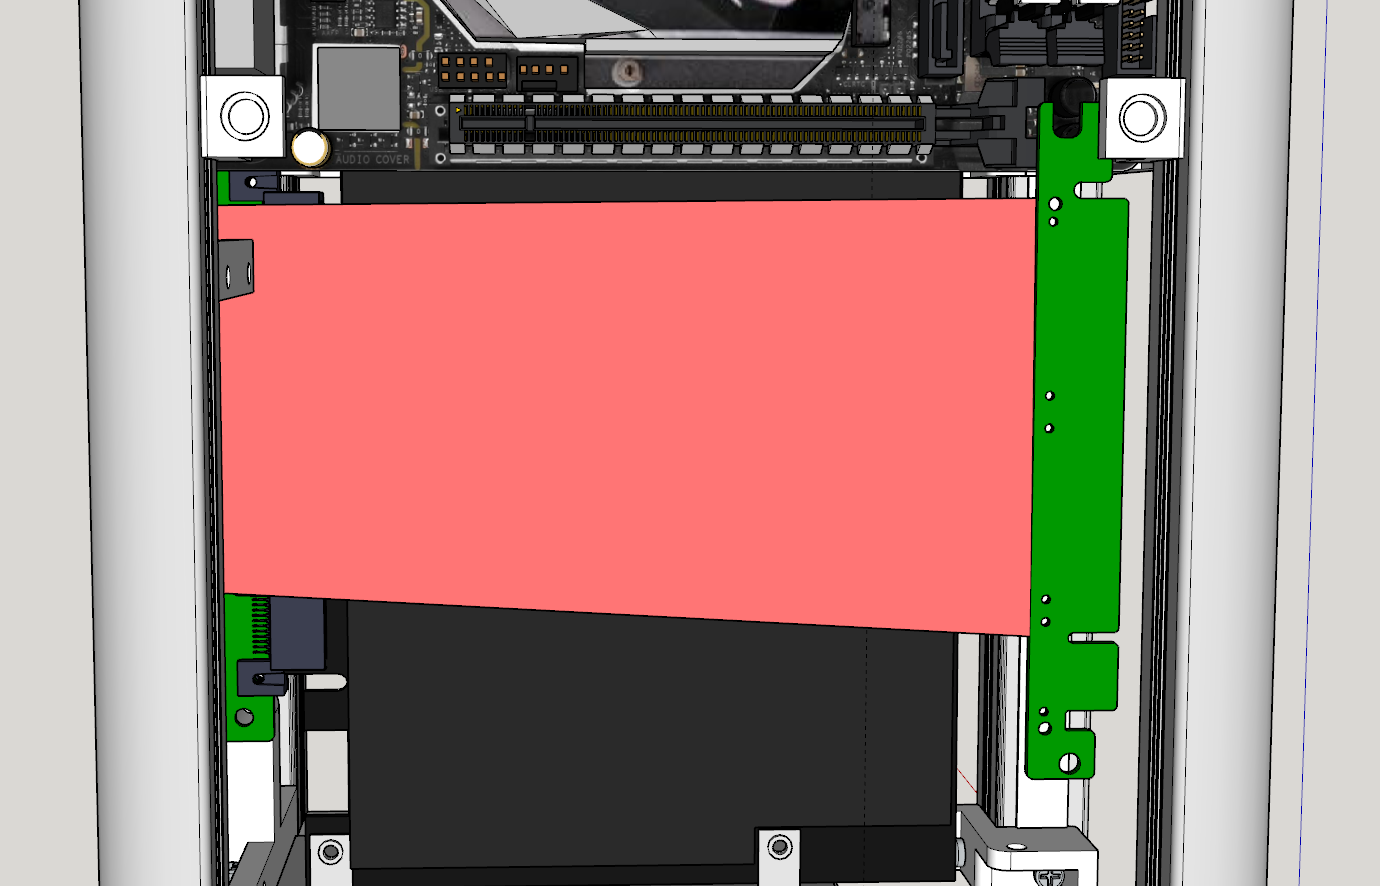
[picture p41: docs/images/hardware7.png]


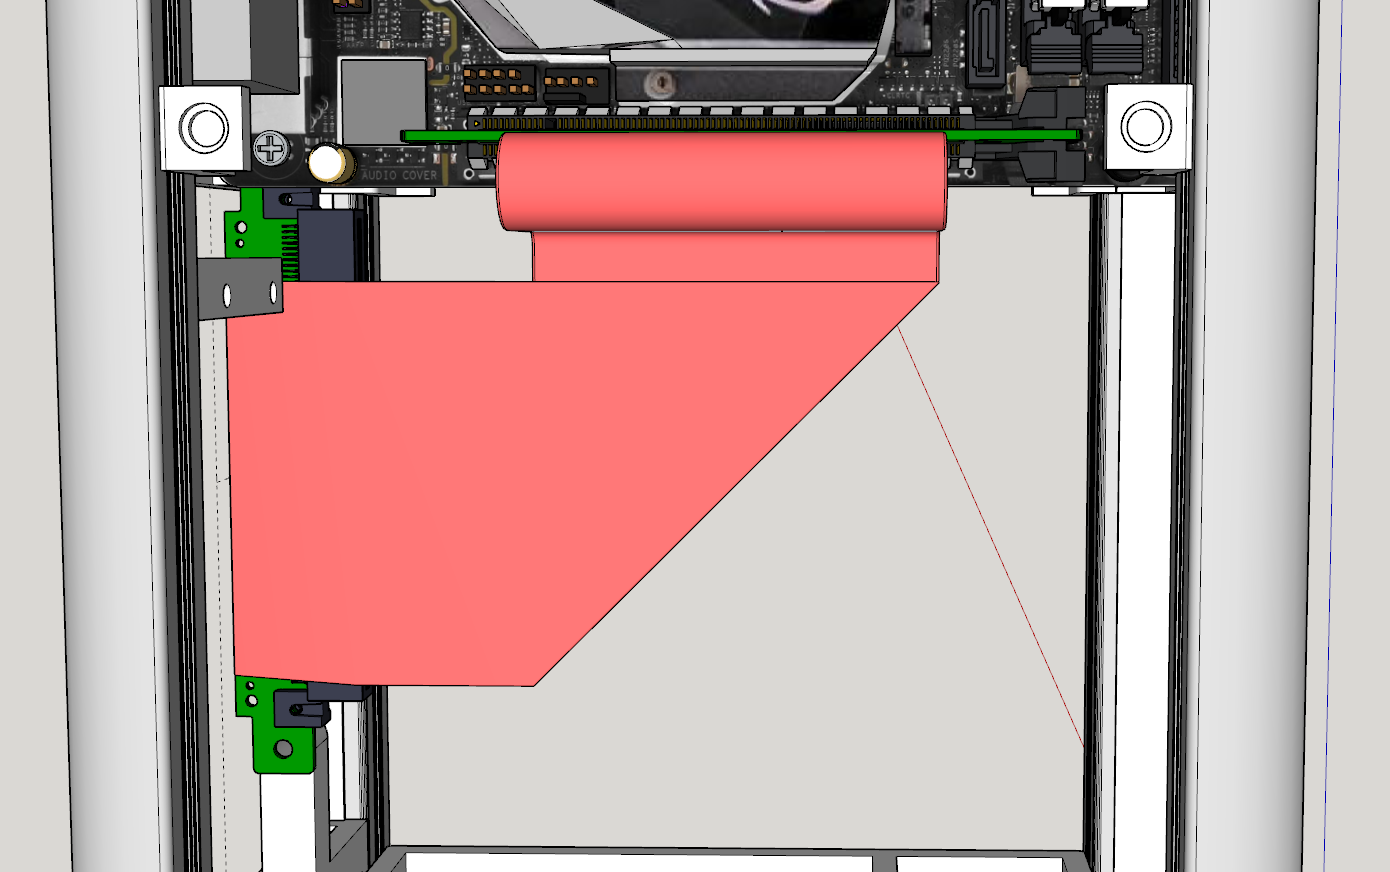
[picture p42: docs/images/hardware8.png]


**PSU**

Next is the PSU. I would advice to already plug in the cables you require before inserting it into the case. Make sure the fan is facing outwards so it doesn't suffocate.

Take care when mounting the PSU to the printed parts as this is the only part that uses 6-32 screws.

When the PSU is inserted, you can route the cables and insert the into the components. There is some room in front of the PSU for excess cabling when using a standard SFX PSU.

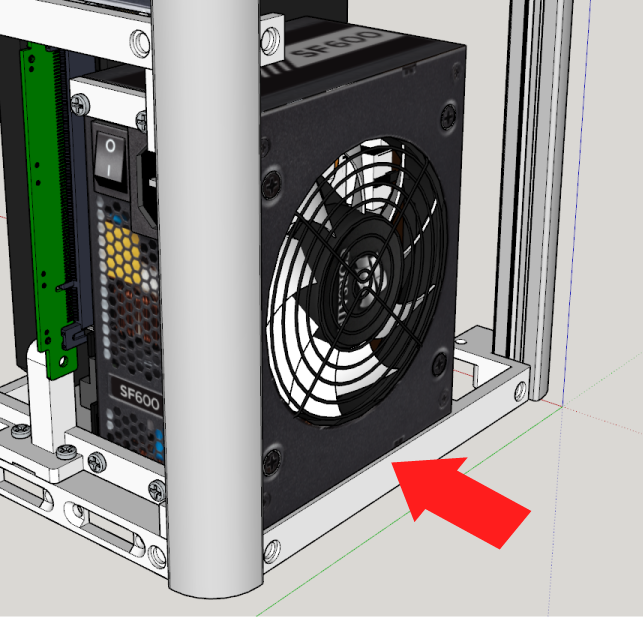
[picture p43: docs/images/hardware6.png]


**Final accesories**

We're almost ready now, only some minor things left. The video output extensions can be mounted to the case and inserterd in the GPU. It requires countersunk M4 screws. Don't overtighten countersunk screws as they will break the plastic parts!!

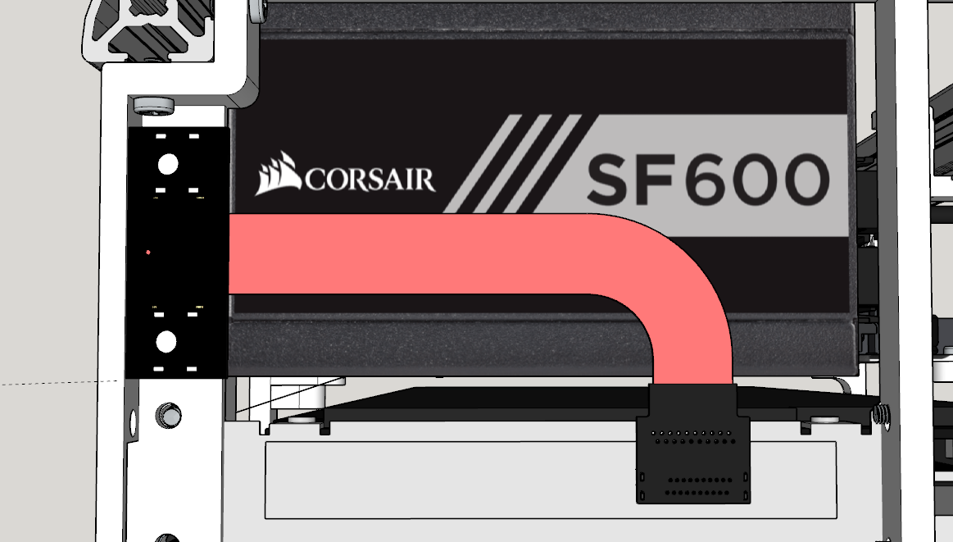
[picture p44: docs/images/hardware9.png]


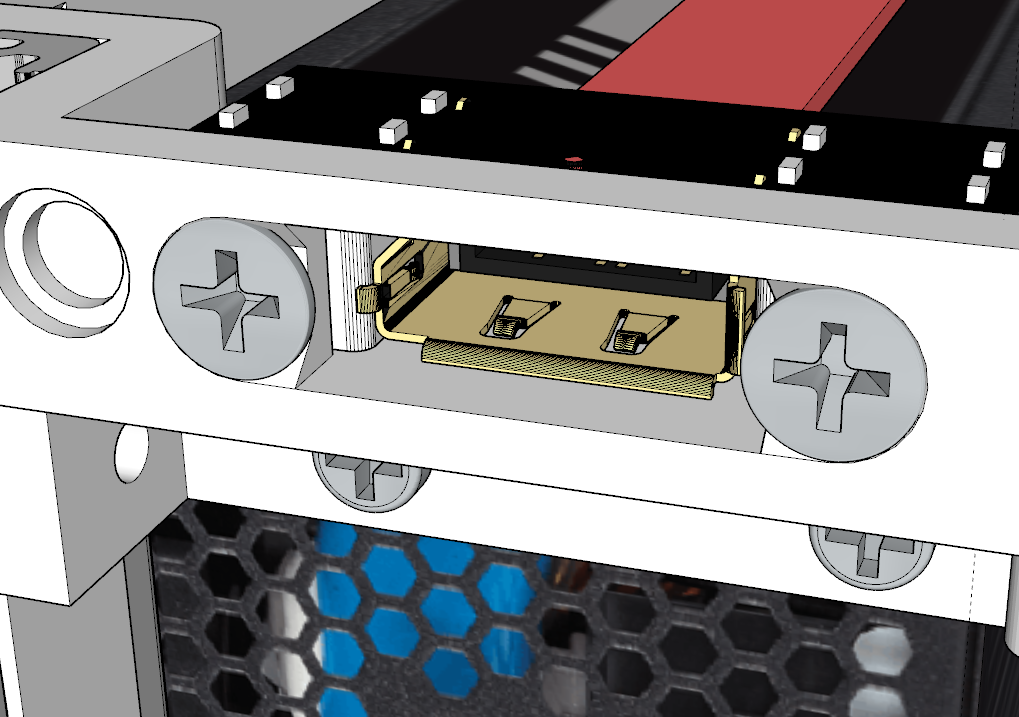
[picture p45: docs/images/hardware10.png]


Now is the time to reinsert the top printed part and mount fourth screw of the motherboard in the mount. They should line up if everything went well.

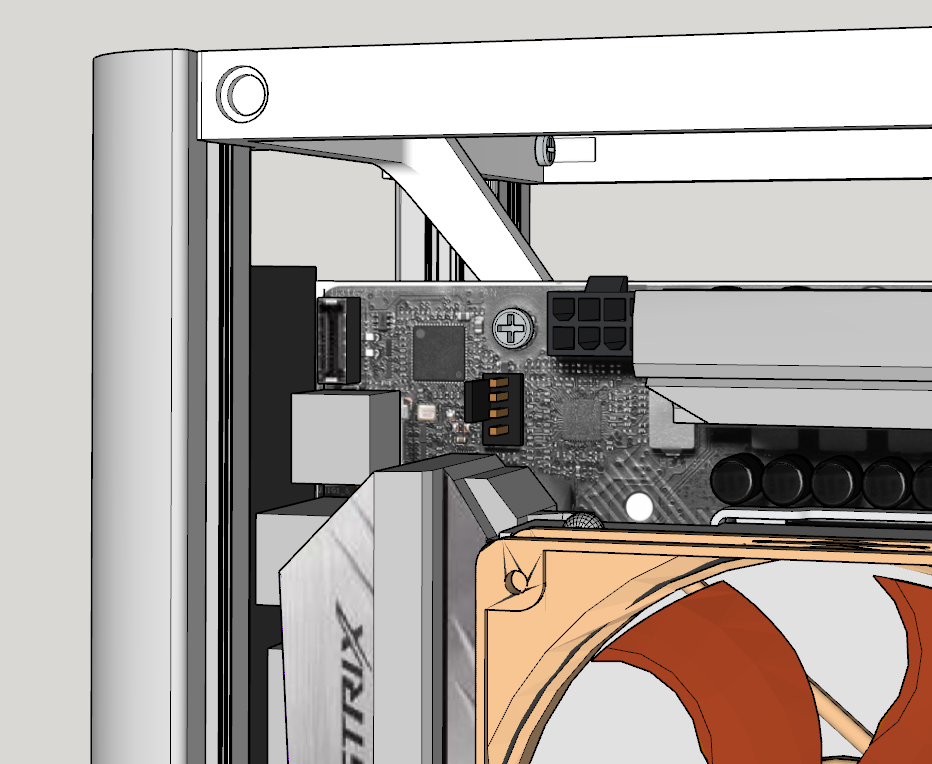
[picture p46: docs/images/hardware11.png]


We're gonna start attaching panels now. The top panel is first, but some things need to be mounted to it first. Use you 16mm vandal switch in the front and mount it with the bolt that comes with it.

The (optional) top fan is next. It mount to the top panel using self tapping screws in the 4 screw holes. You may want to countersink the holes if you got a drill with a countersinking bit to make it look better.

Wen everything is mounted, you can carefuly drop the panel down into the case and screw it to the extrusions using M6 screws (or smaller if the tapping on your extrusion isn't M6).

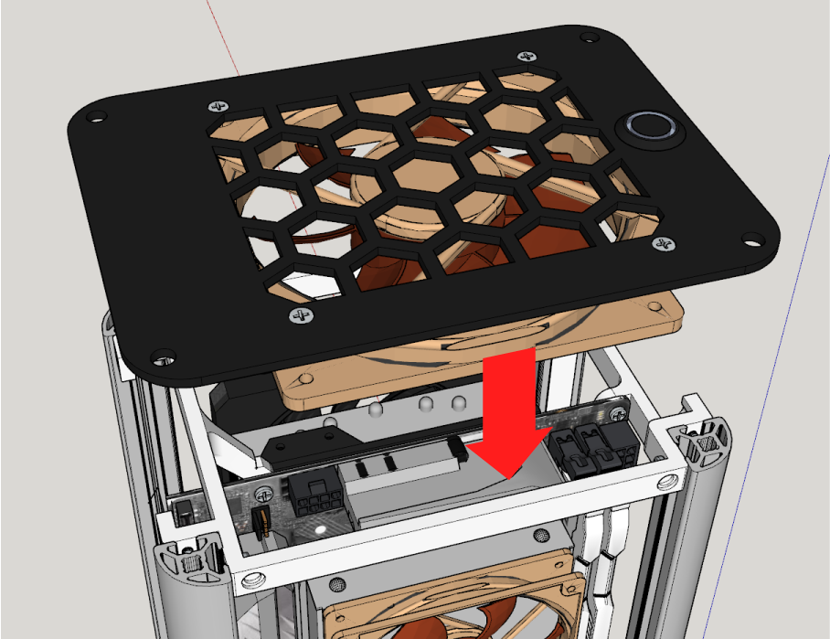
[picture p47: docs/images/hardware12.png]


The bottom is next, which is screws into the extrusion using your choice of case feet.

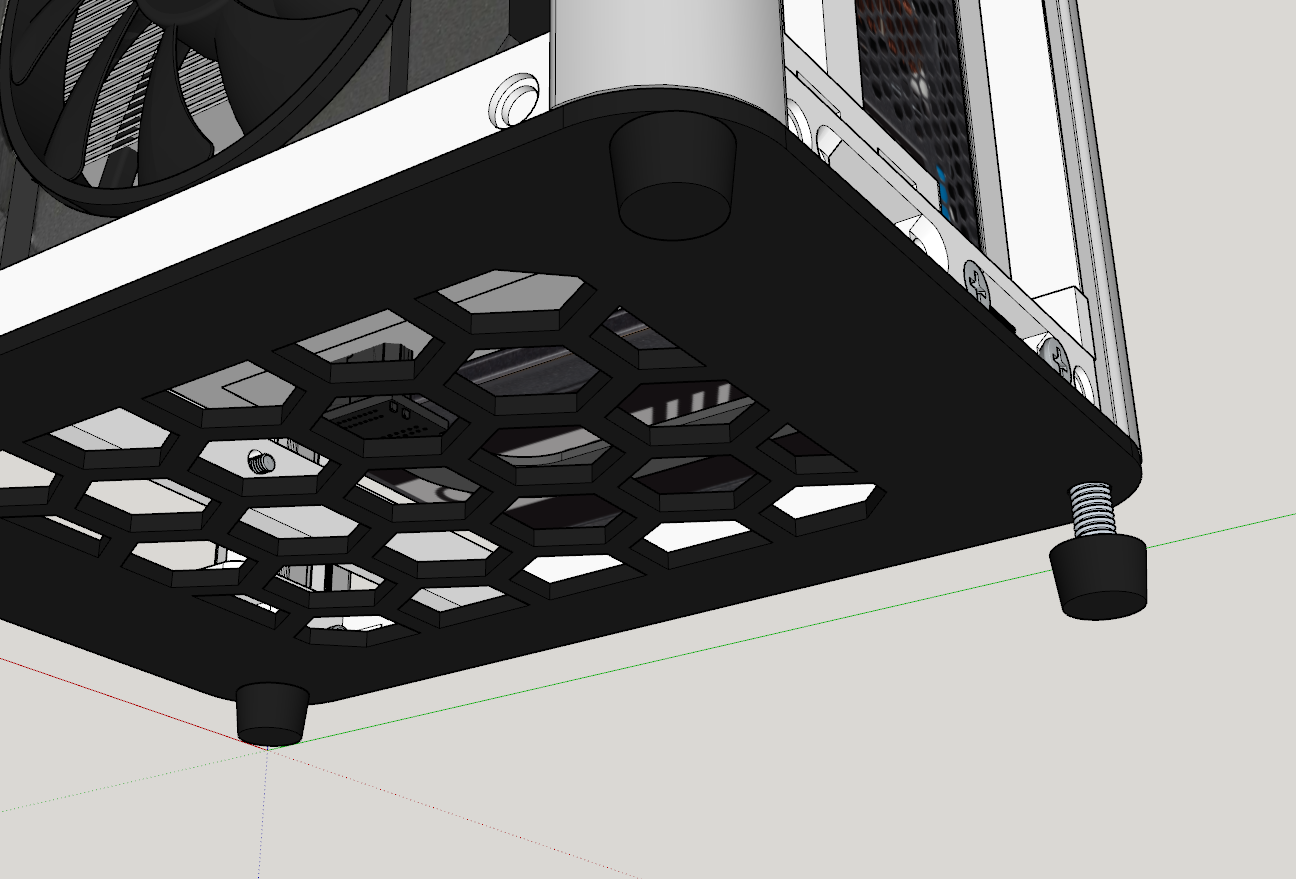
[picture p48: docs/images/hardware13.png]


The remaining panels are attached using the magnets, easy enough.

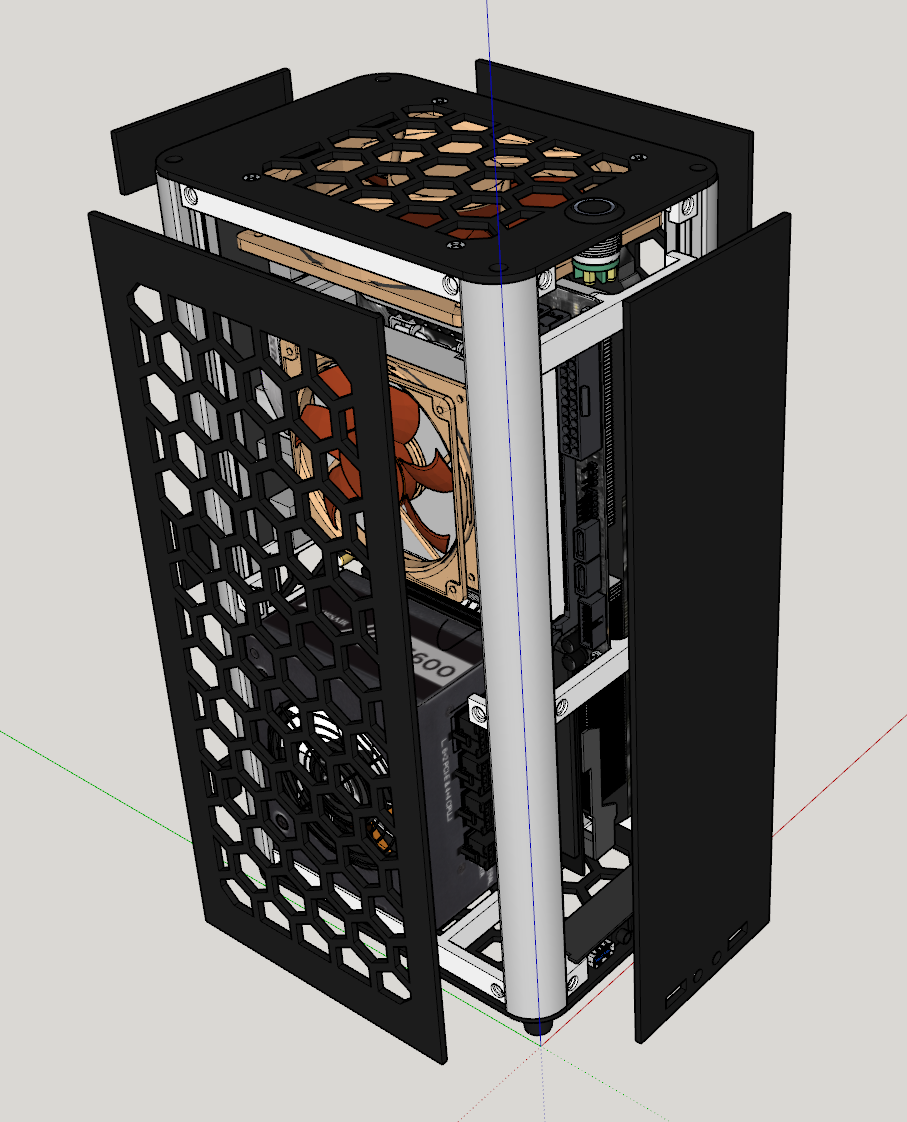
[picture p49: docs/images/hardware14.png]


You are now done, hooray!

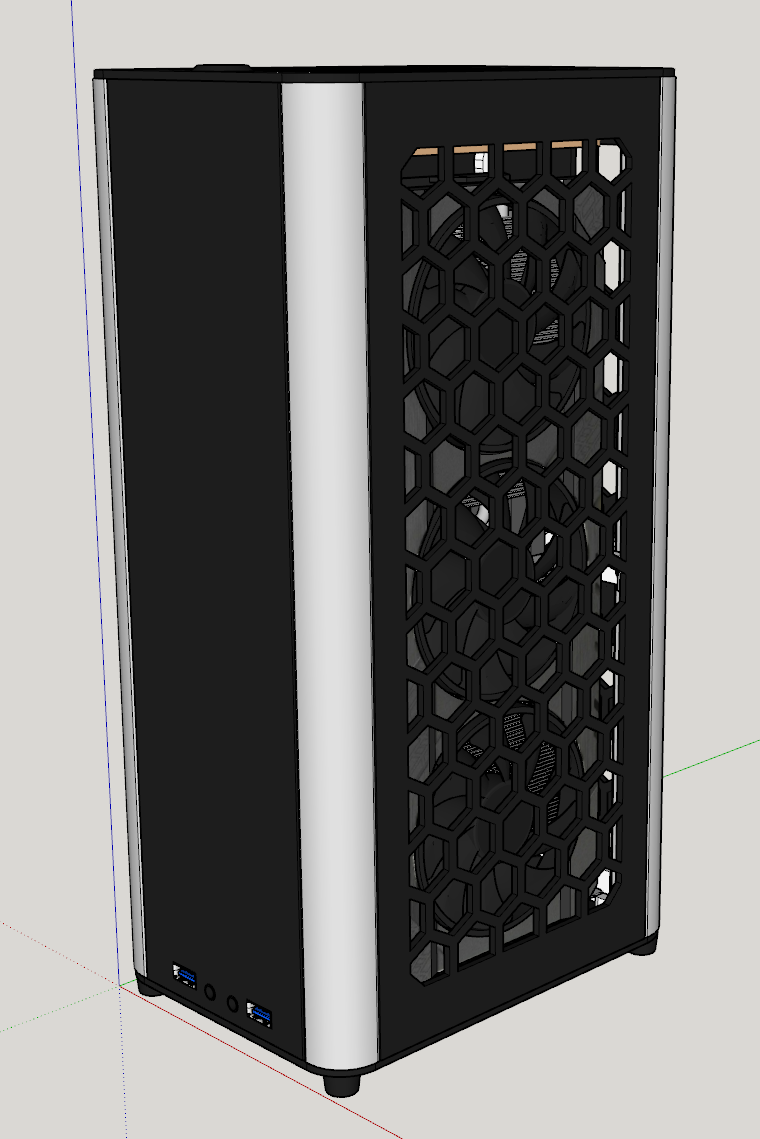
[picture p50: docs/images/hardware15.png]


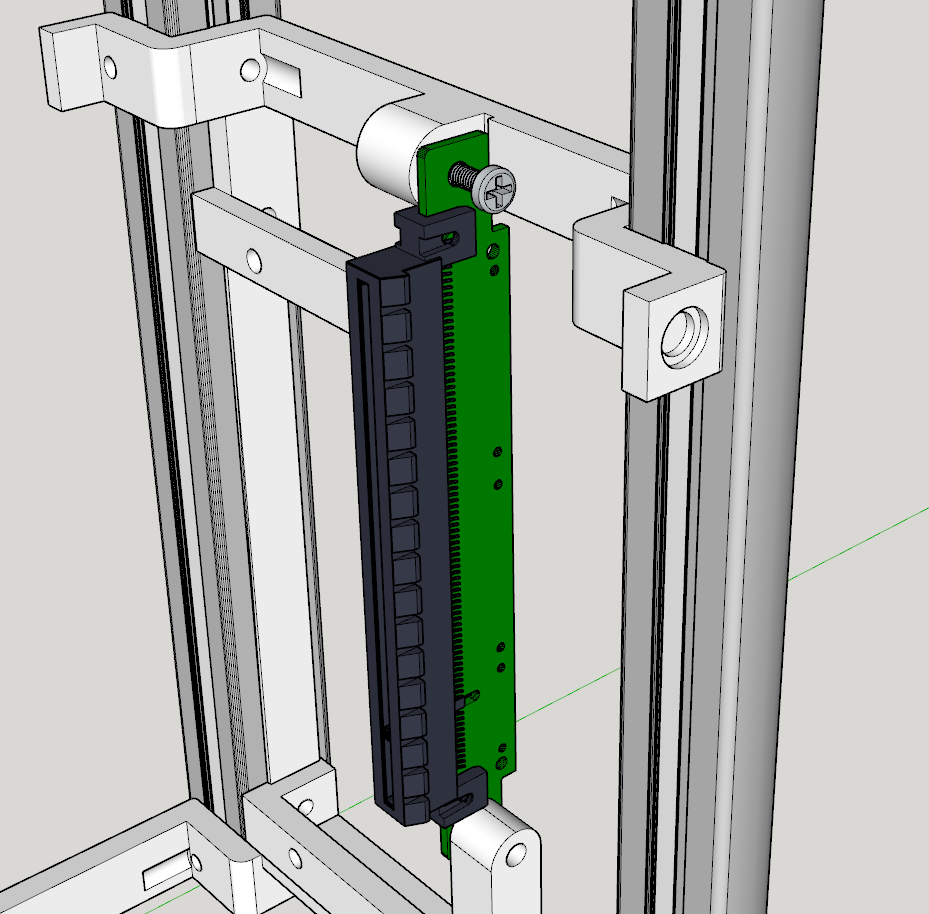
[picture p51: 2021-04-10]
docs/images/assembly8.png

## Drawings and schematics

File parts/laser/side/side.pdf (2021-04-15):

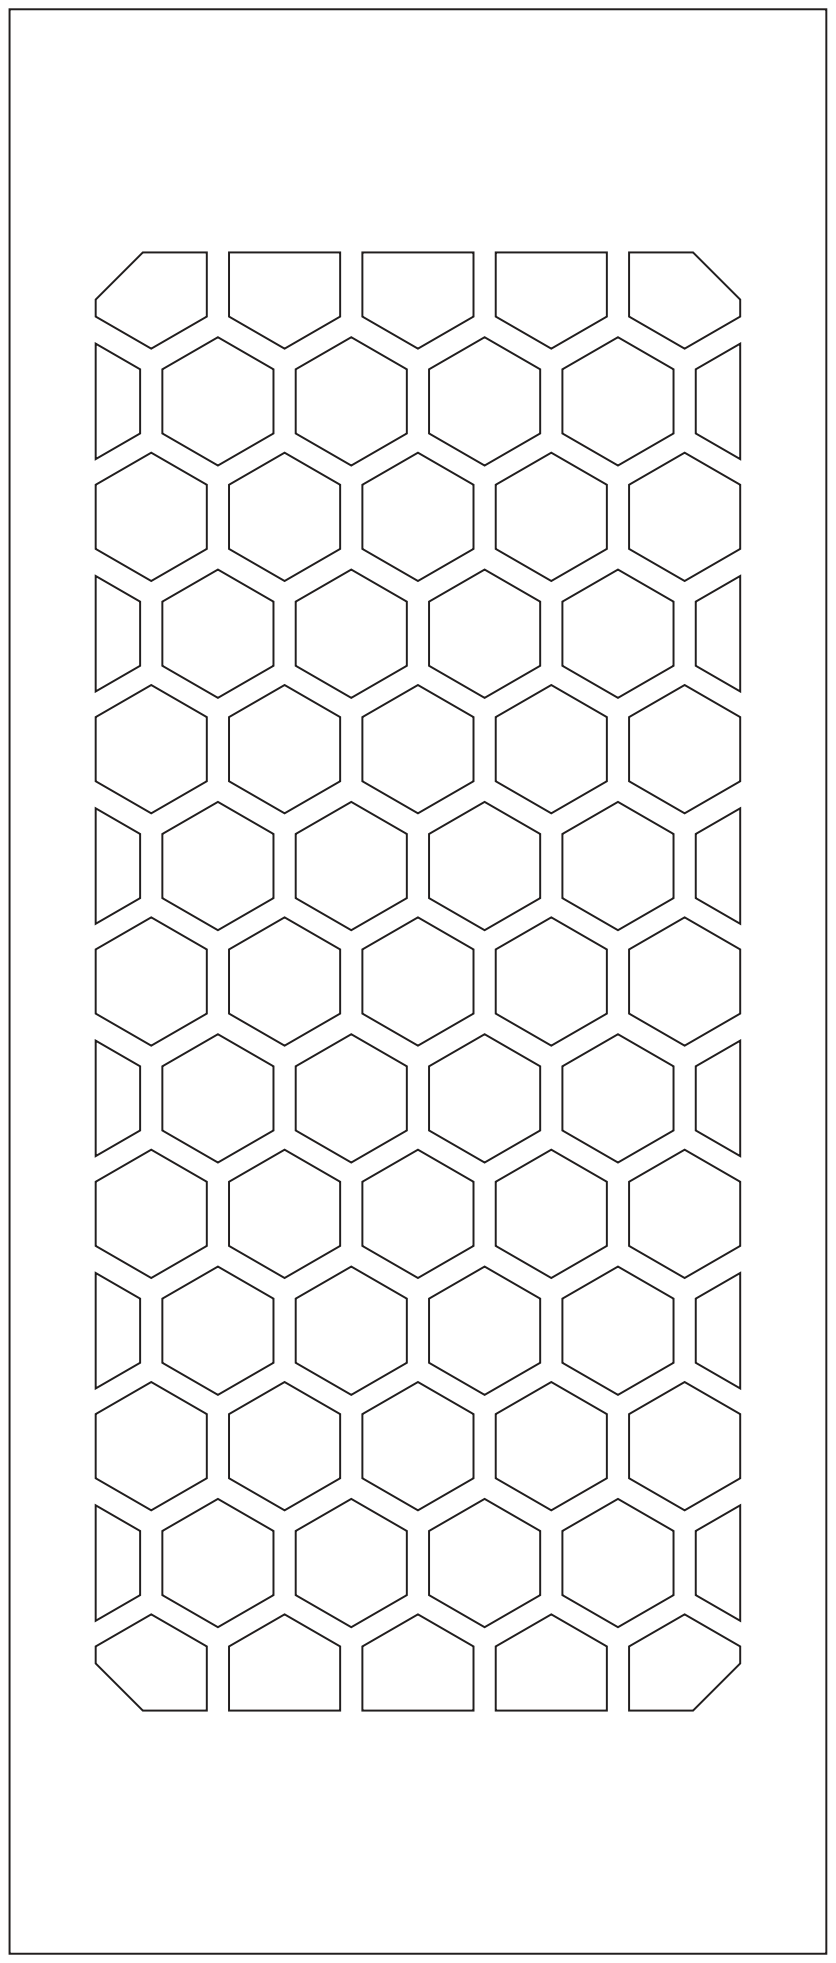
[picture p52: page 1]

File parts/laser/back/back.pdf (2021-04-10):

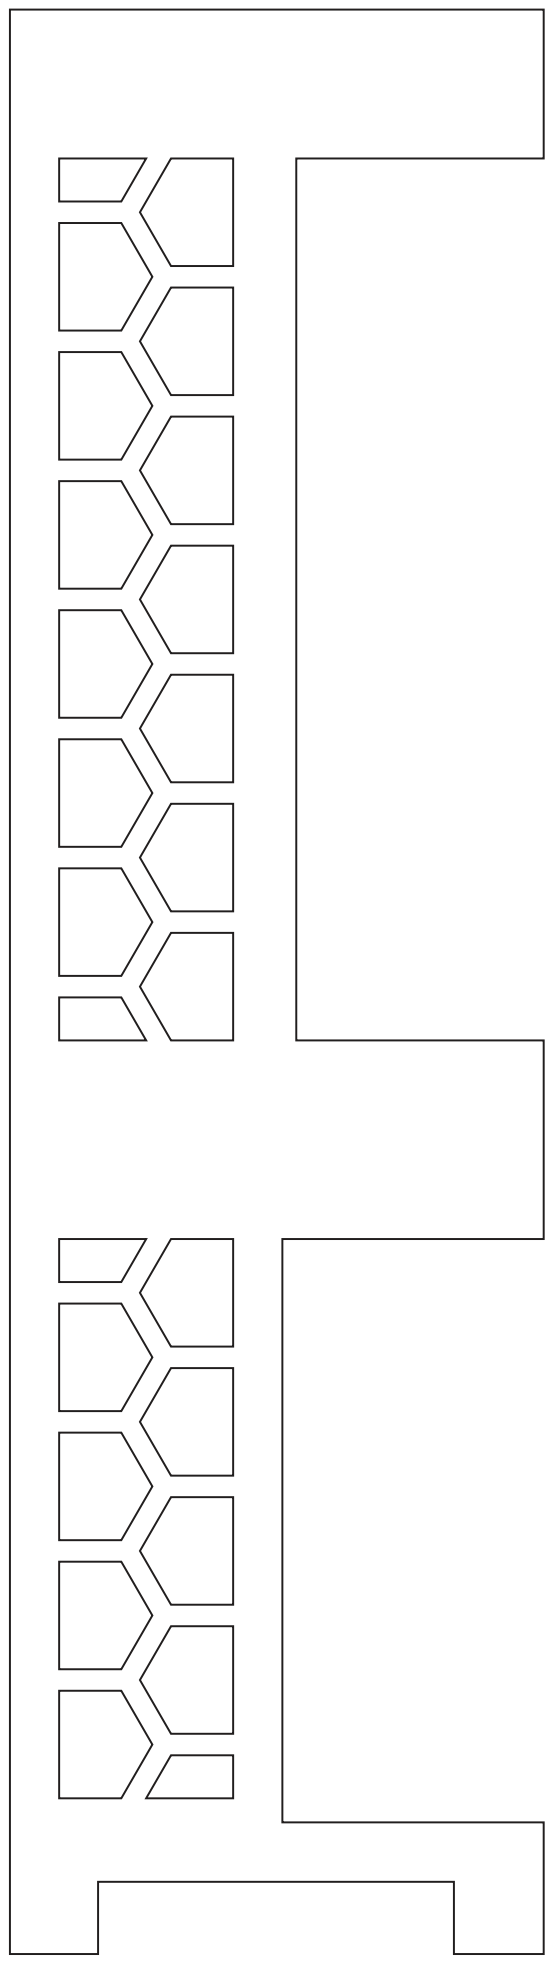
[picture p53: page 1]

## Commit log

2021-02-27 Init bottom part
    [bottom.stl]
2021-03-08 Corrected mounting holes for the PCI clamp
    [bottom.stl]
2021-03-08 Motherboard bottom back part and documentation
    [motherboard bottom back.stl]
2021-03-08 Motherboard bottom front part and documentation
    [motherboard bottom front.stl]
2021-03-08 General 3D printed parts documentation
2021-03-08 PCI bracket clamp part and documentation
    [pci bracket clamp.stl]
2021-03-08 PSU bottom part and documentation
    [psu bottom.stl]
2021-03-08 PSU top part and documentation
    [psu top.stl]
2021-03-08 Correct psu bottom extrusion protrusion
    [psu bottom.stl]
2021-03-08 Motherboard bottom mount corrections
    [motherboard bottom back.stl, motherboard bottom front.stl]
2021-03-08 Top parts and documentation
    [top keycap.stl, top vandal.stl]
2021-03-08 Motherboard top front part and documentation
    [motherboard top front.stl]
2021-03-08 Cable holder part and documentation
    [cable holder.stl]
2021-03-08 Extrusion insert parts and documentation
    [extrusion insert 1.stl, extrusion insert 2.stl, extrusion insert 3.stl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]
2021-03-09 Assembly first draft
2021-04-08 Parts update for revision 2
    [bottom.stl, motherboard bottom back.stl, motherboard bottom front magnet.stl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]
2021-04-08 Extrusion inserts update for revision 2
    [extrusion insert 1.stl, extrusion insert 2.stl, extrusion insert 3.stl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]
2021-04-08 Typo's in assembly doc
2021-04-10 Forgot hole for threaded insert for riser
    [motherboard bottom back.stl]
2021-04-10 Laser parts
2021-04-10 Update to top part and motherboard back bottom
    [motherboard bottom back.stl, top.stl]
2021-04-11 New top part
    [top.stl]
2021-04-11 Top panel fan realignment
2021-04-11 Ran some repairs on the part STL's
    [bottom.stl, motherboard bottom back.stl, motherboard bottom front magnet.stl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]
2021-04-11 Tweaked the extrusion insert STL's
    [extrusion insert 1.stl, extrusion insert 2.stl, extrusion insert 3.stl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]
2021-04-12 Repair another STL and update screenshots
    [motherboard bottom back.stl]
2021-04-14 Update source to offset fan .5mm and include gpu holder
2021-04-14 New GPU holder
    [gpu holder.stl]
2021-04-14 Add readme files for laser cutting
2021-04-14 Offset the top fan .5mm
2021-04-15 Add a fourth mounting hole to gpu holder
    [gpu holder.stl]
2021-04-15 Move magnets So the X and Y offset from panel edge is the same
    [bottom.stl, top.stl]
2021-04-18 Magnet glue documentation
2021-04-18 Glue mold part
2021-04-18 Glue mold STL's
    [glue mold reverse.stl, glue mold.stl]
2021-04-18 Glue images
2021-04-18 Wrong glue images location
